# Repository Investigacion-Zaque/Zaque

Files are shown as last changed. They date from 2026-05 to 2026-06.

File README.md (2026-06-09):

# 🌾 Zaque - Monitoreo Agrícola Local Distribuido

> **Sistema de monitoreo de suelo para campesinos con IoT, sin dependencia de internet**

---

## 🎯 ¿Qué es Zaque?

Zaque es una **red de dispositivos ESP32 que monitorean cultivos** en múltiples puntos de una finca. El campesino enciende la zona móvil del celular, los ESP32 se conectan a esa red local, y puede ver todas las mediciones desde su navegador móvil **sin necesidad de internet**.

| Característica | Ventaja |
|---|---|
| 📡 **WiFi Local** | Sin necesidad de internet |
| 💾 **Almacenamiento Local** | Datos en microSD dentro del dispositivo |
| 📍 **GPS en cada nodo** | Sabe dónde se midió cada dato |
| 📊 **Dashboard web** | Visualiza desde el navegador del celular |
| 🤖 **Recomendaciones inteligentes** | Alertas de riego, fertilización, pH |
| ⚡ **Bajo consumo** | 1-3 meses de batería por nodo |
| 💰 **Bajo costo** | Hardware accesible (~USD $100 por nodo) |

---

## 🏗️ Arquitectura

```
┏━━━━━━━━━━━━━━━━━━━━━━━━━━━━━━━━━━━━━━━━━━┓
┃   Red WiFi Local del Celular 📱         ┃
┗━━━━━━━━━━━━━━━━━━━━━━━━━━━━━━━━━━━━━━━━━━┛
    △           △           △           △
    │           │           │           │
    │           │           │           │
┌───▼──┐    ┌───▼──┐    ┌───▼──┐    ┌─MAIN─┐
│SENSOR│    │SENSOR│    │SENSOR│    │MAIN  │
│  #1  │    │  #2  │    │  #3  │    │NODE  │
│      │    │      │    │      │    │      │
│📍GPS │    │📍GPS │    │📍GPS │    │📍GPS │
│📊SD  │    │📊SD  │    │📊SD  │    │📊SD  │
│🔋BAT │    │🔋BAT │    │🔋BAT │    │🔋BAT │
└───┬──┘    └───┬──┘    └───┬──┘    └─┬────┘
    │ HTTP       │ HTTP       │ HTTP    │ Servidor
    │ POST       │ POST       │ POST    │ Web
    └────────────┼────────────┼────────┘
                 │
                 ▼
        ┏━━━━━━━━━━━━━━━━━┓
        ┃  📊 Dashboard   ┃
        ┃  en Navegador   ┃
        ┃  (celular)      ┃
        ┗━━━━━━━━━━━━━━━━━┛
```

**Componentes:**

- **1 nodo MAIN**: Centro de procesamiento, servidor web, almacenamiento
- **N nodos SENSOR**: Distribuidos en la finca, envían mediciones
- **Red local WiFi**: Creada por el hotspot del celular
- **Almacenamiento**: Todos los datos en microSD local (sin nube)

---

## 📋 Estado del Proyecto (v0.2.0)

| Componente | Estado | Descripción |
|---|---|---|
| **Arquitectura** | ✅ Completado | Migración a local offline |
| **Firmware base** | ✅ Completado | zaque_device.ino con ambos roles |
| **Lectura de sensores** | ✅ Completado | RS485 Modbus (humedad, temp, pH, NPK) |
| **GPS** | ✅ Completado | Fallback a ubicación por defecto |
| **SD Logger** | ✅ Completado | CSV + JSON local |
| **WiFi Manager** | ✅ Completado | Conexión a redes locales |
| **Recomendaciones** | ✅ Completado | Motor de reglas de cultivo |
| **API REST** | 🔜 En progreso | Endpoints POST/GET |
| **Dashboard Web** | 🔜 Próximo | HTML embebido, mapas, históricos |
| **Múltiples sensores** | 🔜 Próximo | Escalabilidad 3+ nodos |
| **Sincronización nube** | 🔜 Futuro | MQTT/API remota opcional |

---

## 📊 Variables Medidas

| Variable | Unidad | Sensor | Rango |
|---|---|---|---|
| **Humedad del suelo** | % | RS485 Modbus | 0-100% |
| **Temperatura del suelo** | °C | RS485 Modbus | -10 a +60°C |
| **Conductividad eléctrica** | mS/cm | RS485 Modbus | 0-10 |
| **Potencial de hidrógeno (pH)** | pH | RS485 Modbus | 3.0-9.0 |
| **Nitrógeno (N)** | mg/kg | RS485 Modbus | 0-999 |
| **Fósforo (P)** | mg/kg | RS485 Modbus | 0-999 |
| **Potasio (K)** | mg/kg | RS485 Modbus | 0-999 |
| **Ubicación** | lat/lon | GPS NEO-6M | - |
| **Nivel de batería** | % | ADC ESP32 | 0-100% |

---

## 🤖 Recomendaciones Inteligentes

El sistema genera **alertas útiles al campesino** basadas en mediciones:

### 🔴 Alertas Críticas
- **Humedad < 25%**: "Riesgo de estrés hídrico severo. Revise riego lo antes posible."
- **Humedad > 85%**: "Riesgo de encharcamiento. Suspenda riego y revise drenaje."
- **Conductividad > 4.0 mS/cm**: "Posible exceso de sales. Suspenda fertilización."

### 🟠 Problemas Moderados
- **Humedad baja + Temperatura alta**: "Estrés hídrico. Revise riego urgentemente."
- **pH ácido + Fósforo bajo**: "Bloqueo nutricional. Revise corrección antes de fertilizar."
- **Humedad alta + Conductividad alta**: "Acumulación de sales. Evite fertilizar."

### 🟢 Recomendaciones Específicas
- **NPK bajo**: "Revise estado del cultivo y considere fertilización."
- **pH fuera de rango**: "Suelo ácido/alcalino. Consulte técnico para corrección."

### ✅ Estado Óptimo
- Cuando todo está bien: "Condiciones óptimas: Mantenga monitoreo."

---

## 🔌 Hardware Recomendado

**Idéntico para MAIN y SENSOR:**

```
┌─────────────────────────────────┐
│ ESP32 DevKit (WiFi + Bluetooth) │
├─────────────────────────────────┤
│ • Microcontrolador dual-core     │
│ • WiFi 802.11b/g/n              │
│ • 4 MB Flash + 520 KB RAM        │
│ • 36 pines GPIO                  │
└─────────────────────────────────┘
         │
    ┌────┴────┐
    │          │
    ▼          ▼
┌─────────┐ ┌─────────────────┐
│ Sensor  │ │ GPS + microSD   │
│ Modbus  │ │ + Batería       │
│ RS485   │ │ + Regulador     │
└─────────┘ └─────────────────┘
```

| Componente | Cantidad | Especificación | Costo |
|---|---|---|---|
| ESP32 DEVKIT | 1 | Microcontrolador WiFi | ~$15 |
| Sensor RS485 | 1 | NPK/Modbus multiparamétrico | ~$50 |
| Módulo GPS | 1 | NEO-6M (9600 bps) | ~$12 |
| microSD | 1 | 32GB FAT32 | ~$8 |
| Batería Li-Ion | 1 | 3.7V 2000mAh con BMS | ~$10 |
| Regulador DC-DC | 1 | 5V → 3.3V | ~$3 |
| **Total por nodo** | - | - | **~$100** |

---

## 📁 Estructura del Repositorio

```
Zaque/
│
├── 📦 firmware/
│   ├── zaque_device/              ← FIRMWARE UNIFICADO (MAIN/SENSOR)
│   │   ├── zaque_device.ino       ← Archivo principal
│   │   ├── config.h               ← Configuración (roles, pines, WiFi)
│   │   ├── types.h                ← Estructuras de datos e interfaces
│   │   ├── sensor_reader.cpp      ← Lectura RS485 Modbus
│   │   ├── gps_reader.cpp         ← Lectura GPS + fallback
│   │   ├── sd_logger.cpp          ← Logging en microSD
│   │   ├── wifi_manager.cpp       ← Gestión WiFi local
│   │   ├── http_client.cpp        ← Cliente HTTP (SENSOR)
│   │   ├── web_server.cpp         ← Servidor web (MAIN)
│   │   ├── node_registry.cpp      ← Registro de nodos (MAIN)
│   │   ├── recommendations.cpp    ← Motor de recomendaciones
│   │   └── dashboard_html.h       ← HTML/CSS/JS embebido
│   │
│   ├── Prueba_SD/                 ← Test de tarjeta SD
│   ├── Prueba_Sensor/             ← Test de sensor Modbus
│   └── legacy/                    ← Código anterior (referencia)
│
├── 📚 docs/
│   ├── arquitectura_offline_multinodo.md
│   ├── pinout.md
│   ├── protocolo_api_local.md
│   ├── hardware.md
│   ├── formato_sd.md
│   └── plan_migracion.md
│
├── 📄 Articulo/                   ← Artículo académico LaTeX
│   └── main.tex
│
├── 📋 README.md                   ← Este archivo
├── 📋 GUIA_FLASHEO_Y_USO.md       ← Guía de instalación
├── 📋 ZAQUE_RECOMMENDATION_ENGINE.md
├── 📋 informe_migracion_zaque_offline_multinodo.md
├── 📋 PIN_OUT.txt
└── 📋 LICENSE
```

---

## 🚀 Inicio Rápido

### 1️⃣ Configurar Firmware MAIN

```cpp
// En config.h:
#define DEVICE_ROLE DEVICE_ROLE_MAIN        // ✓ MAIN
#define NODE_ID "zaque"
#define NODE_NAME "Nodo principal - Casa finca"
#define WIFI_SSID "Zaque"                   // Tu zona móvil
#define WIFI_PASSWORD "free12345"
#define DEFAULT_LATITUDE 4.6632              // Ubicación por defecto (GPS fallback)
#define DEFAULT_LONGITUDE -74.0550
```

**En Arduino IDE:**
- Abrir: `firmware/zaque_device/zaque_device.ino`
- Seleccionar: Board → ESP32 Dev Module
- Puerto: COM/ttyUSB
- Subir

### 2️⃣ Configurar Firmware SENSOR

```cpp
// En config.h:
#define DEVICE_ROLE DEVICE_ROLE_SENSOR      // ✓ SENSOR
#define NODE_ID "zona_2"
#define NODE_NAME "Lote de maiz"
#define MAIN_HOST "zaque.local"             // IP/hostname del MAIN
```

Cambiar y subir a otro ESP32.

### 3️⃣ Ejecutar en Campo

```
1. Enciende zona móvil del celular ("Zaque")
2. Enciende ESP32 MAIN
   └─→ Se conecta a WiFi
   └─→ Levanta servidor en http://zaque.local
   └─→ Toma medición local
   └─→ Espera sensores
3. Enciende ESP32 SENSOR(es)
   └─→ Se conectan a WiFi
   └─→ Toman mediciones
   └─→ Envían al MAIN por HTTP POST
   └─→ Entran en deep sleep (ahorro energía)
4. Abre navegador en celular
   └─→ Entra a http://zaque.local
   └─→ Ve dashboard con todos los nodos
   └─→ Lee recomendaciones
```

---

## 📡 API REST Local

### Endpoints del MAIN

| Método | Ruta | Descripción |
|---|---|---|
| **GET** | `/` | Dashboard HTML interactivo |
| **GET** | `/api/status` | Estado general del sistema |
| **GET** | `/api/nodes` | Lista de nodos activos |
| **GET** | `/api/latest` | Última medición por nodo |
| **POST** | `/api/measurements` | Recibir medición (SENSOR → MAIN) |
| **GET** | `/download/measurements.csv` | Descargar histórico |

### Ejemplo: Enviar Medición

```bash
curl -X POST http://zaque.local/api/measurements \
  -H "Content-Type: application/json" \
  -d '{
    "api_key": "ZAQUE_LOCAL_KEY",
    "node_id": "zona_2",
    "node_name": "Lote de maiz",
    "latitude": 4.6632,
    "longitude": -74.0550,
    "soil_humidity": 64.0,
    "soil_temperature": 22.5,
    "electrical_conductivity": 1.2,
    "ph": 6.2,
    "nitrogen": 34,
    "phosphorus": 18,
    "potassium": 41,
    "battery_percent": 83
  }'
```

---

## 💾 Almacenamiento en microSD

**Archivos creados automáticamente:**

```
/measurements.csv
  timestamp,node_id,node_name,lat,lon,soil_temperature,soil_humidity,...
  1715609400,zona_2,Lote de maiz,4.6632,-74.0550,22.5,64.0,...

/latest.json
  {
    "updated_at": "1715609400",
    "nodes": [
      {
        "node_id": "zona_2",
        "soil_humidity": 64.0,
        "ph": 6.2,
        "recommendation": "✅ Condiciones óptimas: Mantenga monitoreo."
      }
    ]
  }

/logs/system.log
  [DEBUG] GPS reader initialized
  [INFO] Measurement logged to SD
  [WARNING] Battery low: 15%
```

---

## ⚡ Consumo de Energía

### Nodo SENSOR típico
```
Medición:      ~5 seg
Envío HTTP:    ~2 seg
Deep Sleep:    ~30 min

Consumo promedio: ~0.5 mA (en deep sleep)
Batería típica:   2000 mAh
Autonomía:        ≈ 1-3 meses
```

### Nodo MAIN (siempre activo)
```
WiFi siempre conectado
Dashboard activo
Consumo: ~80-150 mA promedio

Nota: MAIN debe estar conectado a alimentación (AC/solar)
```

---

## 🔐 Seguridad

| Aspecto | MVP (Actual) | Futuro |
|---|---|---|
| **Red** | WiFi local | WiFi local + VPN opcional |
| **API Key** | Hardcodeada | JWT tokens |
| **HTTPS** | No necesario | Sí, cuando haya internet |
| **Autenticación** | Ninguna | Por nodo |
| **Datos** | Almacenamiento local | Encriptación opcional |

---

## 📚 Documentación Completa

| Documento | Contenido |
|---|---|
| 📖 **`docs/arquitectura_offline_multinodo.md`** | Detalles arquitectura distribuida |
| 🔌 **`docs/pinout.md`** | Asignación de pines ESP32 y conflictos |
| 📡 **`docs/protocolo_api_local.md`** | Especificación completa de API |
| 🔧 **`docs/hardware.md`** | Recomendaciones y esquemáticos |
| 💾 **`docs/formato_sd.md`** | Estructura de archivos SD |
| 📋 **`docs/plan_migracion.md`** | Fases de implementación |
| 🤖 **`ZAQUE_RECOMMENDATION_ENGINE.md`** | Motor de recomendaciones |
| 📊 **`informe_migracion_zaque_offline_multinodo.md`** | Informe técnico completo |
| 🚀 **`GUIA_FLASHEO_Y_USO.md`** | Paso a paso de instalación |

---

## 🛠️ Desarrollo Local

### Compilar en Arduino IDE

```bash
# Abrir archivo
Arduino IDE → File → Open → firmware/zaque_device/zaque_device.ino

# Configurar placa
Tools → Board → ESP32 Dev Module
Tools → Port → /dev/ttyUSB0 (o COM3 en Windows)

# Compilar y subir
Sketch → Upload (Ctrl+U)
```

### Ver logs

```bash
# Monitor serial en Arduino IDE
Tools → Serial Monitor
Configurar: 115200 baud
```

### Debug

```cpp
// En config.h:
#define ENABLE_DEBUG_SERIAL true        // Habilita logs

// En código:
#if ENABLE_DEBUG_SERIAL
  Serial.println("✓ Mi mensaje de debug");
#endif
```

---

## 🎯 Próximas Fases

### 🔜 Phase 1: MAIN Autónomo
- [x] Lectura sensor Modbus
- [x] Lectura GPS
- [x] Almacenamiento SD
- [ ] Servidor web básico
- [ ] Dashboard HTML

### 🔜 Phase 2: API Local
- [ ] Endpoint POST /api/measurements
- [ ] Validación de datos
- [ ] Manejo de errores

### 🔜 Phase 3: Firmware SENSOR
- [ ] Lectura de sensores
- [ ] Envío HTTP al MAIN
- [ ] Deep sleep

### 🔜 Phase 4: Escalabilidad
- [ ] Soporte 3+ nodos
- [ ] Descubrimiento automático (mDNS)
- [ ] Sincronización de estado

### 🔜 Phase 5: Recomendaciones
- [ ] Motor de reglas completo
- [ ] Análisis predictivo
- [ ] Recomendaciones por cultivo

### 🔜 Phase 6-7: Futuro
- [ ] Sincronización con nube (opcional)
- [ ] IA para predicción
- [ ] Interfaz mejorada

---

## 📞 Preguntas Frecuentes

| Pregunta | Respuesta |
|---|---|
| **¿Necesito internet?** | No. Zaque funciona 100% offline con red WiFi local del celular. |
| **¿Cuánto cuesta?** | ~$100 USD por nodo (hardware accesible). |
| **¿Cuántos sensores?** | Teóricamente ilimitados. Límite práctico: rango WiFi (~50m). |
| **¿Si falla GPS?** | Se usa ubicación por defecto automáticamente, sin alertas. |
| **¿Se pierden datos sin internet?** | No. Todo se guarda localmente en microSD. |
| **¿Compatible con otros sensores?** | Sí, arquitectura modular permite integrar RS485/Modbus. |

---

## 📄 Licencia

```
ZAQUE - Sistema de Monitoreo Agrícola Local Distribuido
Copyright (C) 2026 Alejandro Roa, Laura Holguín, Andrés Guarnizo

This program is free software: you can redistribute it and/or modify
it under the terms of the GNU General Public License as published by
the Free Software Foundation, either version 3 of the License.
```

Ver [LICENSE](LICENSE) para más detalles.

---

## 👥 Autores

- 🧑‍💻 **Alejandro Roa Aparicio** – Desarrollo firmware, arquitectura
- 👩‍💼 **Laura Sofía Holguín Giraldo** – Análisis agrícola, documentación
- 🔧 **Andrés Felipe Guarnizo Saavedra** – Hardware, integración sensores

---

<div align="center">

**🌾 Zaque: Empoderando a campesinos con tecnología accesible 🌾**

*Monitoreo inteligente, local, sin dependencia de internet.*

[📖 Documentación Completa](docs/) • [📱 Hardware](docs/hardware.md) • [🚀 Inicio Rápido](#-inicio-rápido) • [🤖 Recomendaciones](ZAQUE_RECOMMENDATION_ENGINE.md)

</div>

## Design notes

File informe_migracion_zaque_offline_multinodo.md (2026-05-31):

# Informe técnico: Migración de Zaque hacia una red local multinodo con dashboard offline

## 1. Resumen ejecutivo

El proyecto **Zaque** actualmente está planteado como un sistema de monitoreo ambiental de suelos para comunidades campesinas de Colombia. La arquitectura actual usa nodos ESP32 que miden variables del suelo y envían datos mediante **ESP-NOW** hacia un receptor/gateway, el cual publica la información por **MQTT** hacia un servidor Node.js y una base de datos MySQL.

La nueva versión propuesta cambia el enfoque hacia una arquitectura **local, autónoma y tolerante a falta de internet**, donde un campesino pueda encender la zona móvil de su celular, conectar varios dispositivos ESP32 a esa red local y visualizar las mediciones de diferentes puntos de la finca desde una página web levantada por un nodo principal.

La propuesta consiste en migrar el proyecto hacia una arquitectura con:

- Un **nodo MAIN**, que funciona como estación principal.
- Varios **nodos SENSOR**, que funcionan como puntos distribuidos de medición.
- Mismo hardware para todos los dispositivos.
- Diferencia únicamente por firmware o configuración.
- Comunicación por WiFi local usando la red del celular.
- Dashboard web servido desde el nodo MAIN.
- Almacenamiento local en microSD.
- GPS en cada nodo para georreferenciar las mediciones.
- Recomendaciones agrícolas básicas por zona.
- MQTT y nube como modo opcional futuro, no como dependencia principal.

---

## 2. Estado actual del repositorio

Según la estructura actual del repositorio, Zaque contiene los siguientes módulos principales:

```text
Zaque/
├── ESP32/
├── Base de datos/
├── Api/
├── Frontend/
├── Backend/
├── README.md
└── LICENSE
```

El README actual describe una arquitectura basada en:

```text
[ESP32 Emisor] ──ESP-NOW──> [ESP32 Receptor] ──MQTT──> [Servidor Node.js] ──> [MySQL]
```

Los componentes actuales relevantes son:

| Componente actual | Estado | Uso actual |
| --- | ---: | --- |
| `ESP32/ESPNOW_bajo_consumo_emisor.ino`  | Funcional | Nodo sensor que lee RS485/Modbus, envía por ESP-NOW y entra en deep sleep. |
| `ESP32/Receptor_con_MQTT_y_Bateria.ino` | Funcional | Nodo receptor/gateway que recibe ESP-NOW y publica por MQTT. |
| `Base de datos/server.js` | Funcional | Servidor Node.js con cliente MQTT y persistencia en MySQL. |
| `Api/` | Pendiente | REST API futura. |
| `Frontend/` | Pendiente | Dashboard futuro. |
| `Backend/` | Pendiente | Lógica de negocio futura. |

La versión actual ya tiene una base valiosa:

- Lectura de sensor NPK por RS485/Modbus.
- Comunicación entre ESP32.
- Medición de batería.
- Deep sleep para bajo consumo.
- Separación entre nodo sensor y nodo receptor.
- Backend inicial para recibir datos por MQTT.

Sin embargo, el nuevo objetivo requiere reducir la dependencia de internet y de infraestructura externa.

---

## 3. Nuevo objetivo del proyecto

El nuevo objetivo de Zaque es convertirse en una **red local de monitoreo agrícola distribuido**, donde un campesino pueda consultar información del suelo de diferentes zonas de su finca sin depender de internet.

La nueva idea central es:

> Un conjunto de dispositivos ESP32 con el mismo hardware, distribuidos en distintos puntos de una finca. Uno de ellos se configura como nodo MAIN y levanta un dashboard web local. Los demás se configuran como nodos SENSOR y envían sus mediciones al MAIN mediante la red WiFi creada por el celular del campesino. Cada nodo guarda sus datos localmente en microSD y reporta mediciones georreferenciadas con GPS.

---

## 4. Arquitectura propuesta

### 4.1 Arquitectura general

```text
Red WiFi local del celular
                                  │
                                  │
        ┌─────────────────────────┼─────────────────────────┐
        │                         │                         │
        ▼                         ▼                         ▼
┌─────────────────┐       ┌─────────────────┐       ┌─────────────────┐
│ ESP32 SENSOR 1  │       │ ESP32 SENSOR 2  │       │ ESP32 SENSOR N  │
│ Sensor suelo    │       │ Sensor suelo    │       │ Sensor suelo    │
│ GPS             │       │ GPS             │       │ GPS             │
│ microSD         │       │ microSD         │       │ microSD         │
│ Batería         │       │ Batería         │       │ Batería         │
└────────┬────────┘       └────────┬────────┘       └────────┬────────┘
         │                         │                         │
         │ HTTP/JSON               │ HTTP/JSON               │ HTTP/JSON
         └─────────────────────────┼─────────────────────────┘
                                   ▼
                         ┌─────────────────┐
                         │ ESP32 MAIN      │
                         │ Sensor suelo    │
                         │ GPS             │
                         │ microSD         │
                         │ Web dashboard   │
                         │ API local       │
                         │ Recomendaciones │
                         └────────┬────────┘
                                  │
                                  │ HTTP local
                                  ▼
                         ┌─────────────────┐
                         │ Celular         │
                         │ Navegador web   │
                         │ Dashboard Zaque │
                         └─────────────────┘
```

### 4.2 Roles del sistema

#### Nodo MAIN

El nodo MAIN es un dispositivo completo. No es solo un gateway; también mide su propia zona.

Funciones:

- Conectarse al WiFi del celular.
- Leer su propio sensor de suelo.
- Leer GPS.
- Guardar sus propias mediciones en microSD.
- Levantar un servidor web local.
- Exponer una API HTTP para recibir datos de otros nodos.
- Guardar las mediciones recibidas de los nodos SENSOR.
- Calcular o asignar recomendaciones agrícolas básicas.
- Mostrar dashboard con todos los puntos de medición.
- Permitir descarga de archivos CSV o JSON.

#### Nodo SENSOR

El nodo SENSOR tiene el mismo hardware que el MAIN, pero ejecuta un firmware distinto o una configuración diferente.

Funciones:

- Conectarse al WiFi del celular.
- Leer sensor de suelo.
- Leer GPS.
- Guardar copia local en microSD.
- Buscar o conocer la IP del nodo MAIN.
- Enviar mediciones por HTTP/JSON al nodo MAIN.
- Reintentar envío si falla.
- Dormir entre mediciones para ahorrar batería.

---

## 5. Decisión clave: mismo hardware, firmware diferente

Una de las mejores decisiones del nuevo diseño es que todos los dispositivos compartan el mismo hardware:

```text
ESP32 + sensor de suelo RS485/Modbus + GPS + microSD + batería
```

La diferencia se define por software:

```cpp
#define DEVICE_ROLE_MAIN 1
#define DEVICE_ROLE_SENSOR 2

#define DEVICE_ROLE DEVICE_ROLE_MAIN
// #define DEVICE_ROLE DEVICE_ROLE_SENSOR
```

Ventajas:

- Simplifica compras y ensamblaje.
- Facilita mantenimiento.
- Permite reemplazar un MAIN por un SENSOR cambiando firmware.
- Permite escalar de 1 nodo a muchos nodos.
- Reduce errores de cableado por diseños diferentes.
- Facilita documentar un solo diagrama de hardware.

---

## 6. Comparación entre arquitectura actual y nueva arquitectura

| Aspecto | Arquitectura actual | Nueva arquitectura propuesta |
| --- | --- | --- |
| Comunicación entre nodos | ESP-NOW | WiFi local del celular + HTTP/JSON |
| Salida principal de datos | MQTT hacia servidor | Dashboard web local en el MAIN |
| Dependencia de internet | Alta | Baja o nula |
| Almacenamiento | MySQL en servidor | microSD local en MAIN y sensores |
| Visualización | Frontend pendiente | Web embebida en ESP32 MAIN |
| Escalabilidad local | Emisor + receptor | 1 MAIN + muchos SENSOR |
| GPS | No central en diseño actual | GPS por nodo |
| Recomendaciones | Backend futuro | Reglas locales por zona |
| Uso en campo sin internet | Limitado | Principal objetivo |
| Nube/MQTT | Principal | Opcional futuro |

---

## 7. Flujo de operación propuesto

### 7.1 Flujo para el campesino

```text
1. El campesino prende la zona móvil del celular.
2. Enciende el nodo MAIN.
3. Enciende los nodos SENSOR distribuidos en la finca.
4. Todos los ESP32 se conectan a la red WiFi local del celular.
5. El MAIN levanta el dashboard web.
6. Los SENSOR toman mediciones y las envían al MAIN.
7. El campesino abre el navegador del celular.
8. Entra a la IP del MAIN o a zaque.local si mDNS funciona.
9. Visualiza mediciones, coordenadas, batería y recomendaciones por zona.
```

### 7.2 Flujo técnico del nodo MAIN

```text
Inicio
  ↓
Cargar configuración
  ↓
Inicializar sensor RS485/Modbus
  ↓
Inicializar GPS
  ↓
Inicializar microSD
  ↓
Conectarse al WiFi del celular
  ↓
Levantar servidor web
  ↓
Levantar API local
  ↓
Tomar medición propia
  ↓
Guardar medición propia en SD
  ↓
Recibir mediciones de sensores
  ↓
Guardar mediciones recibidas
  ↓
Actualizar archivo resumen
  ↓
Mostrar dashboard
```

### 7.3 Flujo técnico del nodo SENSOR

```text
Inicio
  ↓
Cargar configuración del nodo
  ↓
Inicializar sensor RS485/Modbus
  ↓
Inicializar GPS
  ↓
Inicializar microSD
  ↓
Conectarse al WiFi del celular
  ↓
Encontrar MAIN
  ↓
Tomar medición
  ↓
Guardar medición local en SD
  ↓
Enviar medición al MAIN por HTTP POST
  ↓
Si envío correcto: marcar como sincronizado
  ↓
Si envío falla: dejar pendiente para reintento
  ↓
Entrar en deep sleep
```

---

## 8. Comunicación entre SENSOR y MAIN

### 8.1 Protocolo recomendado

Para esta nueva versión, se recomienda usar:

```text
WiFi local + HTTP + JSON
```

Motivos:

- Es fácil de implementar.
- Es fácil de depurar con navegador, Postman o curl.
- Se integra naturalmente con el servidor web del MAIN.
- Permite que los sensores usen una API clara.
- Facilita migrar después a una API externa o sincronización en nube.

### 8.2 Rutas HTTP sugeridas en el MAIN

```text
GET  /
GET  /dashboard
GET  /api/status
GET  /api/nodes
GET  /api/measurements/latest
GET  /api/history?node_id=zona_1
POST /api/measurements
GET  /download/measurements.csv
```

### 8.3 Payload JSON enviado por cada SENSOR

```json
{
  "node_id": "zona_2",
  "node_name": "Lote de maiz",
  "role": "sensor",
  "timestamp": "2026-05-30T16:20:00",
  "lat": 4.7112,
  "lon": -74.0721,
  "soil_temperature": 22.8,
  "soil_humidity": 64.0,
  "electrical_conductivity": 820,
  "ph": 6.2,
  "nitrogen": 34,
  "phosphorus": 18,
  "potassium": 41,
  "battery_percent": 83,
  "firmware_version": "0.2.0"
}
```

### 8.4 Respuesta del MAIN

```json
{
  "status": "ok",
  "stored": true,
  "recommendation": "Humedad adecuada y pH dentro de rango aceptable.",
  "server_time": "2026-05-30T16:20:05"
}
```

---

## 9. Descubrimiento del nodo MAIN

Uno de los retos principales es que los nodos SENSOR necesitan saber la dirección IP del MAIN.

Se proponen implementación.

### mDNS

El MAIN se anuncia como:

```text
zaque.local
```

Los sensores intentan enviar a:

```text
http://zaque.local/api/measurements
```

Ventaja:

- Más amigable.
- No requiere conocer IP.

Desventaja:

- Puede fallar en algunos celulares o redes.

## 10. Almacenamiento en microSD

### 10.1 Por qué usar SD en todos los nodos

Aunque el MAIN guarde todos los datos, conviene que cada SENSOR también tenga microSD.

Ventajas:

- Si no hay conexión con el MAIN, el SENSOR no pierde datos.
- Cada nodo tiene respaldo local.
- Se puede recuperar información directamente desde la SD.
- Permite sincronización posterior.
- Mejora la confiabilidad en campo.

### 10.2 Archivos recomendados en el MAIN

```text
/sd/
├── config.json
├── nodes.json
├── latest.json
├── measurements.csv
├── recommendations.csv
└── logs/
    └── system.log
```

### 10.3 Archivos recomendados en cada SENSOR

```text
/sd/
├── config.json
├── local_measurements.csv
├── pending_queue.csv
└── logs/
    └── sensor.log
```

### 10.4 Formato CSV global del MAIN

```csv
timestamp,node_id,node_name,lat,lon,soil_temperature,soil_humidity,electrical_conductivity,ph,nitrogen,phosphorus,potassium,battery_percent,recommendation
2026-05-30T16:20:00,zona_2,Lote de maiz,4.7112,-74.0721,22.8,64,820,6.2,34,18,41,83,"Humedad adecuada y pH aceptable"
```

### 10.5 Archivo `latest.json`

Este archivo facilita que el dashboard cargue rápidamente la última medición de cada nodo.

```json
{
  "updated_at": "2026-05-30T16:20:05",
  "nodes": [
    {
      "node_id": "main",
      "node_name": "Nodo principal",
      "role": "main",
      "lat": 4.7110,
      "lon": -74.0710,
      "soil_humidity": 58,
      "ph": 6.4,
      "nitrogen": 35,
      "phosphorus": 20,
      "potassium": 40,
      "battery_percent": 91,
      "last_seen": "2026-05-30T16:19:00",
      "recommendation": "Condiciones estables."
    },
    {
      "node_id": "zona_2",
      "node_name": "Lote de maiz",
      "role": "sensor",
      "lat": 4.7112,
      "lon": -74.0721,
      "soil_humidity": 64,
      "ph": 6.2,
      "nitrogen": 34,
      "phosphorus": 18,
      "potassium": 41,
      "battery_percent": 83,
      "last_seen": "2026-05-30T16:20:00",
      "recommendation": "Humedad adecuada y pH aceptable."
    }
  ]
}
```

---

## 11. Recomendaciones agrícolas locales

La primera versión no debería intentar usar inteligencia artificial compleja. Se recomienda comenzar con un motor de reglas simple, explicable y fácil de ajustar.

### 11.1 Variables consideradas

- Humedad del suelo.
- pH.
- Conductividad eléctrica.
- Nitrógeno.
- Fósforo.
- Potasio.
- Temperatura del suelo.
- Batería del nodo.

### 11.2 Ejemplo de reglas iniciales

```text
Si humedad < umbral_bajo:
  Recomendar revisar riego.

Si pH < 5.5:
  Indicar posible acidez del suelo.

Si pH > 7.5:
  Indicar posible alcalinidad del suelo.

Si conductividad es muy alta:
  Alertar posible exceso de sales.

Si N, P o K están bajos:
  Recomendar revisar fertilización según cultivo.

Si batería < 20%:
  Recomendar recargar o revisar alimentación del nodo.
```

### 11.3 Recomendación importante

Las recomendaciones deben mostrarse como orientación, no como diagnóstico absoluto.

Texto sugerido para el dashboard:

> Las recomendaciones son orientativas y deben ajustarse según el cultivo, etapa de crecimiento, tipo de suelo y acompañamiento técnico local.

---

## 12. Dashboard web local

### 12.1 Objetivo del dashboard

El dashboard debe ser simple, liviano y funcional en celulares.

Debe permitir:

- Ver todos los nodos conectados.
- Ver última medición por zona.
- Ver coordenadas GPS.
- Ver batería de cada nodo.
- Ver recomendaciones por zona.
- Ver histórico básico.
- Descargar CSV.
- Identificar nodos sin conexión reciente.

### 12.2 Vista principal sugerida

```text
Zaque - Monitoreo local de finca

Resumen:
- Nodos registrados: 4
- Nodos activos: 3
- Alertas: 2
- Última actualización: hace 1 minuto

[MAIN - Casa finca]
Humedad: 58%
PH: 6.4
NPK: 35 / 20 / 40
Batería: 91%
Recomendación: Condiciones estables.

[Zona 2 - Lote de maíz]
Humedad: 34%
PH: 5.3
NPK: 18 / 10 / 24
Batería: 76%
Recomendación: Humedad baja y pH ácido. Revisar riego y corrección del suelo.
```

### 12.3 Mapa offline

Como no se puede depender de Google Maps o mapas online si no hay internet, se recomienda iniciar con dos opciones:

#### Opción básica

Mostrar coordenadas GPS en texto:

```text
Zona 1: 4.7112, -74.0721
Zona 2: 4.7120, -74.0730
```

#### Opción intermedia

Crear un mapa relativo de finca usando las diferencias entre coordenadas:

```text
Zona 2
           ●

Zona 1 ●          ● Zona 3

           ●
         MAIN
```

Este mapa no requiere internet y puede renderizarse con HTML, CSS y JavaScript sencillo.

---

## 13. Nueva estructura recomendada del repositorio

Se recomienda no borrar de inmediato la arquitectura anterior. Lo mejor es migrar progresivamente y dejar el modo MQTT como referencia o modo online futuro.

```text
Zaque/
├── firmware/
│   ├── zaque_device/
│   │   ├── zaque_device.ino
│   │   ├── config.h
│   │   ├── roles.h
│   │   ├── sensor_reader.cpp
│   │   ├── sensor_reader.h
│   │   ├── gps_reader.cpp
│   │   ├── gps_reader.h
│   │   ├── sd_logger.cpp
│   │   ├── sd_logger.h
│   │   ├── wifi_manager.cpp
│   │   ├── wifi_manager.h
│   │   ├── http_client.cpp
│   │   ├── http_client.h
│   │   ├── web_server.cpp
│   │   ├── web_server.h
│   │   ├── recommendations.cpp
│   │   ├── recommendations.h
│   │   ├── node_registry.cpp
│   │   ├── node_registry.h
│   │   └── dashboard_html.h
│   │
│   └── legacy/
│       ├── ESPNOW_bajo_consumo_emisor.ino
│       └── Receptor_con_MQTT_y_Bateria.ino
│
├── docs/
│   ├── arquitectura_offline_multinodo.md
│   ├── hardware.md
│   ├── pinout.md
│   ├── protocolo_api_local.md
│   ├── formato_sd.md
│   ├── recomendaciones.md
│   └── plan_migracion.md
│
├── dashboard/
│   ├── prototype.html
│   ├── styles.css
│   └── app.js
│
├── tools/
│   ├── csv_to_json.py
│   └── sd_validator.py
│
├── cloud_optional/
│   ├── mqtt_bridge/
│   ├── api/
│   └── database/
│
├── README.md
└── LICENSE
```

### 13.1 Qué hacer con las carpetas actuales

| Carpeta actual | Acción recomendada |
| --- | --- |
| `ESP32/` | Migrar a`firmware/legacy/` y crear `firmware/zaque_device/`. |
| `Base de datos/` | Mover a`cloud_optional/mqtt_bridge/` o mantener como modo online. |
| `Api/` | Usar para futura API externa, no para MVP offline. |
| `Frontend/` | Usar como prototipo visual; la versión embebida debe vivir en`dashboard_html.h`. |
| `Backend/` | Reservar para lógica futura de nube o sincronización. |
| `README.md` | Actualizar con la nueva arquitectura offline multinodo. |

---

## 14. Firmware unificado por roles

### 14.1 Archivo `config.h`

```cpp
#pragma once

#define DEVICE_ROLE_MAIN 1
#define DEVICE_ROLE_SENSOR 2

#define DEVICE_ROLE DEVICE_ROLE_MAIN

#define NODE_ID "main"
#define NODE_NAME "Nodo principal - Casa finca"
#define FIRMWARE_VERSION "0.2.0"

#define WIFI_SSID "NombreZonaMovil"
#define WIFI_PASSWORD "ClaveZonaMovil"

#define MAIN_HOST "zaque.local"
#define MAIN_IP_FALLBACK "192.168.43.50"
#define MAIN_PORT 80

#define MEASUREMENT_INTERVAL_MINUTES 30
```

Para un sensor:

```cpp
#define DEVICE_ROLE DEVICE_ROLE_SENSOR
#define NODE_ID "zona_2"
#define NODE_NAME "Lote de maiz"
```

### 14.2 Pseudocódigo principal

```cpp
#include "config.h"
#include "sensor_reader.h"
#include "gps_reader.h"
#include "sd_logger.h"
#include "wifi_manager.h"
#include "recommendations.h"

#if DEVICE_ROLE == DEVICE_ROLE_MAIN
#include "web_server.h"
#include "node_registry.h"
#endif

#if DEVICE_ROLE == DEVICE_ROLE_SENSOR
#include "http_client.h"
#endif

void setup() {
  initSerial();
  initSensor();
  initGPS();
  initSD();
  connectWiFi();

#if DEVICE_ROLE == DEVICE_ROLE_MAIN
  initNodeRegistry();
  startWebServer();
#endif
}

void loop() {
  Measurement m = readMeasurement();
  m.recommendation = buildRecommendation(m);
  saveMeasurementToSD(m);

#if DEVICE_ROLE == DEVICE_ROLE_MAIN
  updateLocalNode(m);
  handleWebServer();
#endif

#if DEVICE_ROLE == DEVICE_ROLE_SENSOR
  bool sent = sendMeasurementToMain(m);
  if (!sent) {
    savePendingMeasurement(m);
  }
  goToDeepSleep(MEASUREMENT_INTERVAL_MINUTES);
#endif
}
```

---

## 15. Migración del código actual

### 15.1 Reutilizar del emisor actual

Del archivo actual del emisor ESP-NOW se puede reutilizar:

- Inicialización del sensor RS485/Modbus.
- Lectura de variables del suelo.
- Cálculo de batería.
- Estructura de medición.
- Lógica de deep sleep.

Cambios necesarios:

- Reemplazar envío ESP-NOW por HTTP POST.
- Agregar GPS.
- Agregar microSD.
- Agregar reintento de envío.
- Agregar cola de datos pendientes.

### 15.2 Reutilizar del receptor actual

Del archivo actual del receptor con MQTT se puede reutilizar:

- Idea de gateway central.
- Manejo de WiFi.
- Manejo de datos recibidos.
- Estructura de publicación de datos.

Cambios necesarios:

- Reemplazar publicación MQTT por almacenamiento en SD.
- Agregar servidor web embebido.
- Agregar API HTTP local.
- Agregar lectura del sensor propio del MAIN.
- Agregar GPS propio.
- Agregar dashboard.

### 15.3 Reutilizar del backend Node.js

El servidor Node.js actual no debe ser eliminado. Se recomienda moverlo a una carpeta de modo online opcional.

Uso futuro:

- Sincronización cuando haya internet.
- Carga de CSV históricos.
- Panel web en nube.
- Respaldo de datos.
- Análisis avanzado.

---

## 16. Plan de migración por fases

### Fase 1: MAIN autónomo de un solo nodo

Objetivo:

```text
Un solo ESP32 mide, guarda en SD y levanta web local.
```

Tareas:

- Integrar lectura del sensor actual.
- Agregar GPS.
- Agregar microSD.
- Crear archivo CSV local.
- Levantar servidor web simple.
- Mostrar última medición.

Resultado esperado:

```text
ESP32 MAIN → Dashboard local con su propia medición
```

### Fase 2: API local del MAIN

Objetivo:

```text
Permitir que otros nodos envíen mediciones al MAIN.
```

Tareas:

- Crear endpoint `POST /api/measurements`.
- Validar JSON recibido.
- Guardar medición en `measurements.csv`.
- Actualizar `latest.json`.
- Responder con recomendación.

Resultado esperado:

```text
curl o Postman puede enviar una medición falsa al MAIN y aparece en el dashboard.
```

### Fase 3: Firmware SENSOR

Objetivo:

```text
Un nodo SENSOR mide y envía datos reales al MAIN.
```

Tareas:

- Configurar firmware como SENSOR.
- Conectar al WiFi del celular.
- Leer sensor y GPS.
- Guardar localmente en SD.
- Enviar JSON al MAIN.
- Implementar reintento si falla.
- Implementar deep sleep.

Resultado esperado:

```text
SENSOR → HTTP POST → MAIN → SD → Dashboard
```

### Fase 4: Múltiples sensores

Objetivo:

```text
Escalar a 3 o más puntos de medición.
```

Tareas:

- Crear IDs únicos por nodo.
- Mostrar tarjetas por nodo.
- Detectar último contacto.
- Marcar nodos inactivos.
- Mostrar batería por nodo.

Resultado esperado:

```text
Dashboard con MAIN + SENSOR 1 + SENSOR 2 + SENSOR 3
```

### Fase 5: Recomendaciones por zona

Objetivo:

```text
Mostrar alertas y recomendaciones por nodo.
```

Tareas:

- Crear `recommendations.cpp`.
- Definir reglas base.
- Asociar recomendaciones a cada medición.
- Mostrar nivel de alerta.

Resultado esperado:

```text
Cada zona muestra estado: estable, atención, crítico.
```

### Fase 6: Descubrimiento automático del MAIN

Objetivo:

```text
Evitar depender de IP fija.
```

Tareas:

- Implementar mDNS `zaque.local`.
- Implementar fallback por IP.
- Implementar UDP discovery si mDNS falla.

Resultado esperado:

```text
Los sensores encuentran al MAIN automáticamente.
```

### Fase 7: Sincronización opcional con nube

Objetivo:

```text
Recuperar MQTT/API solo cuando haya internet.
```

Tareas:

- Crear módulo opcional `cloud_sync`.
- Subir CSV o JSON a servidor.
- Reusar servidor Node.js actual.
- Mantener modo offline como prioridad.

Resultado esperado:

```text
Zaque funciona sin internet, pero puede sincronizar cuando haya conexión.
```

---

## 17. Librerías sugeridas para ESP32

### Para firmware Arduino

```text
ModbusMaster       → sensor RS485/Modbus
TinyGPSPlus        → lectura GPS
SD                 → tarjeta microSD
SPI                → comunicación con SD
WiFi               → conexión al hotspot
WebServer          → servidor HTTP simple
HTTPClient         → envío HTTP desde SENSOR a MAIN
ArduinoJson        → manejo de JSON
ESPmDNS            → zaque.local
```

### Notas

- Si el dashboard crece mucho, considerar `ESPAsyncWebServer`, pero para iniciar basta con `WebServer`.
- `ArduinoJson` debe usarse con documentos pequeños para no saturar memoria.
- El HTML del dashboard debe ser liviano.

---

## 18. Consideraciones de hardware

### 18.1 Hardware base por nodo

Cada nodo tendría:

```text
- ESP32
- Sensor de suelo RS485/Modbus NPK
- Módulo RS485 tipo HW-519 o equivalente
- Módulo GPS
- Módulo microSD
- Batería
- Regulador de voltaje adecuado
- Caja protectora
```

### 18.2 Recomendación de pines

Se debe diseñar un pinout definitivo evitando conflictos entre:

- UART del sensor RS485.
- UART del GPS.
- SPI de la microSD.
- ADC para batería.
- Pines de boot del ESP32.

Ejemplo conceptual:

```text
RS485/Modbus → UART2
GPS          → UART1
microSD      → SPI
Batería      → ADC
```

### 18.3 Riesgos de hardware

- El GPS puede consumir bastante energía.
- La SD puede corromper datos si se apaga durante escritura.
- El sensor RS485 puede requerir alimentación diferente al ESP32.
- El WiFi consume más que ESP-NOW.
- El hotspot del celular puede limitar el número de dispositivos conectados.

---

## 19. Energía y bajo consumo

Para nodos SENSOR se recomienda:

```text
Despertar → conectar WiFi → medir → guardar SD → enviar → dormir
```

Intervalos sugeridos:

```text
15 minutos: monitoreo más frecuente
30 minutos: equilibrio entre datos y batería
60 minutos: mayor autonomía
```

El MAIN probablemente debe permanecer activo mientras el campesino consulta el dashboard. Se puede considerar un modo donde el MAIN también duerma cuando no se necesita la web, pero para el MVP debe permanecer encendido.

---

## 20. Seguridad mínima

Aunque el sistema sea local, conviene implementar seguridad básica.

Recomendaciones:

- No dejar contraseñas reales en GitHub.
- Mantener `secrets.h` fuera del repositorio.
- Usar `secrets_example.h` como plantilla.
- Agregar un token simple para que solo nodos autorizados envíen datos.

Ejemplo:

```json
{
  "api_key": "ZAQUE_LOCAL_KEY",
  "node_id": "zona_2",
  "soil_humidity": 64
}
```

El MAIN rechaza mediciones sin `api_key` válida.

---

## 21. Cambios sugeridos al README

El README debería actualizarse para explicar la nueva visión:

```markdown
# Zaque

Zaque es una red local de monitoreo agrícola distribuido para comunidades campesinas. El sistema permite instalar varios nodos ESP32 en diferentes puntos de una finca para medir variables del suelo, registrar coordenadas GPS, almacenar datos en microSD y visualizar un dashboard web local desde el celular del agricultor, incluso sin conexión a internet.
```

Nueva arquitectura en README:

```text
[SENSOR 1] ─┐
[SENSOR 2] ─┼── WiFi local / HTTP ──> [MAIN + Web + SD] ──> [Celular]
[SENSOR N] ─┘
```

Se debe aclarar que MQTT pasa a ser opcional:

```markdown
La versión anterior basada en MQTT se conserva como modo online opcional para sincronización futura con servidor y base de datos.
```

---

## 22. Backlog técnico recomendado

### Prioridad alta

- Crear firmware unificado con roles MAIN/SENSOR.
- Migrar lectura RS485/Modbus del firmware actual.
- Implementar SD logger.
- Implementar dashboard básico.
- Implementar `POST /api/measurements`.
- Implementar envío HTTP desde SENSOR.
- Definir formato JSON y CSV.

### Prioridad media

- Agregar GPS.
- Agregar recomendaciones por reglas.
- Agregar vista por nodos.
- Agregar descarga CSV.
- Agregar detección de nodos inactivos.
- Agregar mDNS.

### Prioridad baja

- UDP discovery.
- Mapa relativo offline.
- Sincronización con nube.
- Panel avanzado con gráficas.
- Carga automática de datos históricos.

---

## 23. Riesgos del nuevo enfoque

| Riesgo | Impacto | Mitigación |
| --- | ---: | --- |
| El celular limita dispositivos conectados | Medio | Probar con 3-5 nodos; para más nodos usar router local. |
| IP del MAIN cambia | Alto | mDNS, IP fija o UDP discovery. |
| Consumo alto por WiFi/GPS | Alto | Deep sleep en sensores. |
| Corrupción de SD | Medio | Escribir de forma controlada y cerrar archivos. |
| Dashboard pesado | Medio | HTML/CSS/JS liviano. |
| GPS sin señal | Medio | Permitir coordenadas manuales o última coordenada válida. |
| Pérdida de conexión con MAIN | Medio | Guardar cola pendiente en SD. |
| Memoria limitada ESP32 | Medio | JSON pequeño y archivos estáticos simples. |

---

## 24. MVP recomendado

El MVP más realista sería:

```text
1 nodo MAIN
1 nodo SENSOR
Ambos con mismo hardware
Red WiFi creada por celular
MAIN levanta dashboard
SENSOR envía datos por HTTP
MAIN guarda CSV en SD
Dashboard muestra ambos nodos
```

Criterios de éxito:

- El MAIN se conecta al hotspot.
- El dashboard abre desde el celular.
- El MAIN muestra su propia medición.
- El SENSOR envía una medición real.
- El MAIN guarda la medición en SD.
- La web muestra la medición del SENSOR.
- Se puede descargar o consultar el CSV.
- Si el SENSOR no logra enviar, guarda el dato localmente.

---

## 25. Conclusión

La migración propuesta transforma Zaque de una arquitectura dependiente de MQTT, servidor y base de datos en la nube hacia una arquitectura local, autónoma y más adecuada para zonas rurales.

La nueva versión permite que un campesino use únicamente la zona móvil del celular como red local, sin necesidad de internet, para consultar las condiciones del suelo en diferentes puntos de su finca.

La decisión de usar el mismo hardware para todos los nodos y diferenciar únicamente el firmware es una decisión técnica fuerte porque reduce complejidad, facilita mantenimiento y permite escalar el sistema de forma ordenada.

La arquitectura recomendada para la nueva versión es:

```text
Mismo hardware para todos los nodos
+ Firmware MAIN para estación principal
+ Firmware SENSOR para puntos distribuidos
+ WiFi local del celular
+ API HTTP local
+ microSD en todos los nodos
+ dashboard web embebido
+ recomendaciones por reglas
+ MQTT opcional futuro
```

Esta migración conserva lo valioso del proyecto actual, especialmente la lectura de sensores y la lógica de bajo consumo, pero orienta el sistema hacia una solución más útil, demostrable y realista para el contexto rural colombiano.

---

## 26. Referencias

- Repositorio actual de Zaque: https://github.com/Investigacion-Zaque/Zaque/tree/main
- Arquitectura actual documentada en el README del repositorio: ESP32 emisor por ESP-NOW, ESP32 receptor con MQTT, servidor Node.js y MySQL.

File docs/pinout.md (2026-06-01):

# Pinout - Zaque Offline Multinodo

## Resumen

Cada nodo Zaque usa un ESP32 con múltiples módulos externos. Este documento detalla la asignación de pines para toda la arquitectura.

## Diagrama General

```
┌─────────────────────────────────────┐
│          ESP32 DEVKIT               │
│                                     │
│  GPIO 0  ──→ Divisor de tensión     │
│  GPIO 2  ──→ Power control 1        │
│  GPIO 4  ──→ Power control 2        │
│  GPIO 5  ──→ SD CS (SPI)            │
│  GPIO 12 ──→ GPS TX                 │
│  GPIO 13 ──→ GPS RX                 │
│  GPIO 16 ──→ RS485 RX (UART2)       │
│  GPIO 17 ──→ RS485 TX (UART2)       │
│  GPIO 18 ──→ SD MOSI (SPI)          │
│  GPIO 19 ──→ SD MISO (SPI)          │
│  GPIO 23 ──→ SD SCK (SPI)           │
│  A6      ──→ Analog sensor input    │
│                                     │
│ GND/3V3 connections (ver abajo)     │
└─────────────────────────────────────┘
```

## Pines Utilizados

### 1. Control de Potencia (Conservado)

| Pin | Nombre | Propósito | Voltaje | Notas |
|-----|---|---|---|---|
| 0 | GPIO_0 | Divisor de tensión (ADC) | 0-3.3V  | Monitoreo de batería |
| 2 | POWER_PIN | Control de alimentación módulos | 3.3V | Salida digital |
| 4 | POWER_PIN2 | Control de alimentación módulos | 3.3V | Salida digital |

### 2. Sensor de Suelo RS485/Modbus (Conservado)

| Pin | Nombre  | Propósito | Voltaje | Protocolo | Notas |
|-----|---|---|---|---|---|
| 16  | RXD2 | RX UART2 (RS485) | 3.3V | UART/RS485| Modbus slave |
| 17  | TXD2 | TX UART2 (RS485) | 3.3V | UART/RS485| Modbus slave |
| A6  | ANALOG  | Entrada analógica | 0-3.3V  | ADC | Sensor secundario |

### 3. Módulo GPS (Nuevo)

| Pin | Nombre | Propósito | Voltaje | Protocolo | Notas |
|-----|---|---|---|---|---|
| 12  | GPIO_TX_GPS | TX UART1 (GPS RX) | 3.3V | UART 9600bps | GPS entrada |
| 13  | GPIO_RX_GPS | RX UART1 (GPS TX) | 3.3V | UART 9600bps | GPS salida |

### 4. Tarjeta microSD (Nuevo)

| Pin | Nombre | Propósito | Voltaje | Protocolo | Notas |
|-----|---|---|---|---|---|
| 5 | GPIO_CS | Chip Select (SPI) | 3.3V | SPI | Slave select |
| 18  | GPIO_MOSI | MOSI (SPI) | 3.3V | SPI | Master out |
| 19  | GPIO_MISO | MISO (SPI) | 3.3V | SPI | Master in |
| 23  | GPIO_SCK  | Clock (SPI) | 3.3V | SPI | Clock |

### Conflicto GPIO 13: RESUELTO

**Solución implementada**:
- GPS RX: GPIO 13 ✓
- SD SCK: GPIO 23 ✓

Ambas interfaces funcionan sin conflicto.

## Pines Disponibles / No Utilizados

| Pin | Estado | Notas |
|-----|---|---|
| 1 | Libre  | TX serial debug |
| 3 | Libre  | RX serial debug |
| 6-11 | Libres | Disponibles para expansión |
| 14  | Libre  | Disponible |
| 15  | Libre  | Disponible |
| 21-22 | Libres | Disponibles |
| 24-27 | Libres | Disponibles |
| 32-39 | Libres | GPIO32-39 disponibles (algunos para ADC) |

## Alimentación

### Voltajes

- **ESP32**: 3.3V desde regulador
- **Sensor RS485**: Depende del módulo (usualmente 5V con conversor)
- **GPS**: Típicamente 3.3V o 5V (verificar módulo)
- **microSD**: 3.3V
- **ADC batería**: 0-3.3V (incluye divisor de tensión en GPIO 0)

### GND

Todos los módulos deben compartir GND (plano de tierra común).

## Diagrama de Conexión

```
BATERÍA ────┬──→ 5V Regulador ──→ [+5V bus]
            └──→ Divisor (GPIO0) ──→ ADC
                                       
[+5V bus] ──→ Sensor RS485 (vcc)
[+3.3V] ──→ GPS (vcc si 3.3V)
[+3.3V] ──→ microSD (vcc)
[GND] ─────→ Todos los módulos

RS485 ────┬─→ RX GPIO16 (UART2)
          └─→ TX GPIO17 (UART2)

GPS ──────┬─→ RX GPIO13
          └─→ TX GPIO12

microSD ──┬─→ CS GPIO5
          ├─→ SCK GPIO23
          ├─→ MOSI GPIO18
          └─→ MISO GPIO19
```

## Recomendaciones

1. **Hardware**: Reservar soldadura fría para pines 10-12 como alternativa GPS
2. **Testing**: Validar lecturas simultáneas de RS485 y SD
3. **Documentación**: Crear guía de ensamblado con fotos de conexiones

## Referencias

- ESP32 Datasheet: Pin assignments y capacidades
- RS485 Modbus: Protocolo de comunicación con sensor de suelo
- GPS: TinyGPS+ library requerida
- microSD: Librería SD estándar de Arduino

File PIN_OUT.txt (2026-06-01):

PIN OUT del proyecto

Conservar del proyecto anterior:

GPIO 0 = DIVISOR DE TENSION
// Power control
#define POWER_PIN 2
#define POWER_PIN2 4
Sonda multiparametrica:
#define RXD2 16
#define TXD2 17 
const int analogInPin = A6;  // Analog input pin that the potentiometer is attached to
float sensorValue = 0;  // value read from the pot

Añadir nuevos sensores:

GPS:

GPIO 12 = tx_gps
GPIO 13 = rx_gps

Tarjeta SD:

cs = GPIO 5
sck = GPIO 23
mosi = GPIO 18
miso = GPIO 19

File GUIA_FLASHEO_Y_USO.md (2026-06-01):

# 🚀 GUÍA COMPLETA: Cómo Flashear Zaque y Acceder a la Web

## 📋 Requisitos Previos

### Hardware Necesario
- **Placa ESP32 DEVKIT** (o compatible)
- **Cable USB** (tipo A → micro-B para programación)
- **PC/Laptop** con USB disponible
- **Sensor RS485/Modbus NPK** (opcional para datos reales)
- **Módulo GPS NEO-6M** (opcional)
- **Tarjeta microSD** (recomendado)
- **Batería** (para pruebas completas)

### Software Necesario
- **Arduino IDE 1.8.19+** (descargar de arduino.cc)
- **Drivers CH340** (para ESP32 DEVKIT)
- **Git** (opcional, para clonar repositorio)

---

## 🔧 PASO 1: Instalar Arduino IDE y Drivers

### 1.1 Instalar Arduino IDE
```bash
# Windows/Mac: Descargar de https://www.arduino.cc/en/software
# Linux:
wget https://downloads.arduino.cc/arduino-1.8.19-linux64.tar.xz
tar xf arduino-1.8.19-linux64.tar.xz
cd arduino-1.8.19
./install.sh
```

### 1.2 Instalar Soporte para ESP32
1. Abrir Arduino IDE
2. Ir a: **Archivo** → **Preferencias**
3. En "URL de gestor de tarjetas adicionales", agregar:
   ```
   https://dl.espressif.com/dl/package_esp32_index.json
   ```
4. Aceptar y cerrar
5. Ir a: **Herramientas** → **Placa** → **Gestor de tarjetas**
6. Buscar "ESP32" por Espressif Systems
7. Instalar la última versión
8. Seleccionar placa: **Herramientas** → **Placa** → **ESP32 Dev Module**

### 1.3 Instalar Librerías Necesarias
En Arduino IDE, ir a: **Sketch** → **Incluir librería** → **Gestor de librerías**

Buscar e instalar:
- `ModbusMaster` (Rob Tillaart)
- `TinyGPSPlus` (Mikal Hart)
- `ArduinoJson` (Benoit Blanchon) - versión 6.x
- `WebServer` (incluido con ESP32)

---

## 🎯 PASO 2: Configurar el Firmware

### 2.1 Abrir el Proyecto
1. Descargar el repositorio Zaque
2. En Arduino IDE: **Archivo** → **Abrir**
3. Navegar a: `/home/ingeniero/Desktop/Zaque/firmware/zaque_device/`
4. Seleccionar: `zaque_device.ino`

### 2.2 Configurar como MAIN (Nodo Principal)
Editar `config.h` (en el mismo directorio):

```cpp
// Línea 14-15: Asegurar que es MAIN
#define DEVICE_ROLE DEVICE_ROLE_MAIN
// #define DEVICE_ROLE DEVICE_ROLE_SENSOR

// Línea 19-20: Identificación
#define NODE_ID "main"
#define NODE_NAME "Nodo principal - Casa finca"

// Línea 27-28: WiFi local (CAMBIAR CON TUS DATOS)
#define WIFI_SSID "NombreZonaMovil"        // ← Cambiar al nombre de tu zona móvil
#define WIFI_PASSWORD "ClaveZonaMovil"     // ← Cambiar a tu contraseña WiFi
```

### 2.3 Configurar Conexión Serial (Arduino IDE)
1. Conectar ESP32 a la PC con cable USB
2. En Arduino IDE:
   - **Herramientas** → **Puerto** → Seleccionar puerto COM donde aparezca ESP32
   - **Herramientas** → **Velocidad en bauds** → `115200`
   - **Herramientas** → **Placa** → `ESP32 Dev Module`

---

## ⚡ PASO 3: Compilar y Cargar (Flashear)

### 3.1 Compilar
```
En Arduino IDE, presionar: Ctrl+R  (o Sketch → Verificar)
```

Esperar a que compile. Si hay errores:
- Revisar que todas las librerías estén instaladas
- Revisar que config.h esté en el mismo directorio que zaque_device.ino

### 3.2 Flashear a la Placa
```
En Arduino IDE, presionar: Ctrl+U  (o Sketch → Cargar)
```

**Proceso de carga:**
1. Arduino IDE muestra "Esperando a la carga del puerto..."
2. **PRESIONAR EL BOTÓN "BOOT" del ESP32 y mantener presionado**
3. Esperar unos segundos
4. Arduino IDE muestra barra de progreso
5. Cuando termine, soltar el botón BOOT

> ⚠️ Si falla, revisar que el puerto COM sea correcto

---

## 🌐 PASO 4: Verificar Carga Exitosa

### 4.1 Monitorear Puerto Serial
1. En Arduino IDE: **Herramientas** → **Monitor Serial**
2. Deberías ver logs como:
```
=== ZAQUE Initialization ===
Device Role: MAIN
Node ID: main
Firmware: 0.2.0
→ Initializing soil sensor...
→ Initializing GPS...
→ Initializing SD card...
→ Connecting to WiFi...
✓ Initialization complete
✓ WiFi connected
✓ mDNS: main.local
✓ Web server started on port 80
  → http://zaque.local/
```

Si ves estos mensajes, **¡está funcionando!** ✅

### 4.2 Solucionar Problemas Comunes

| Problema | Causa | Solución |
|---|---|---|
| "Esperando carga..." infinitamente | Puerto incorrecto | Revisar puerto COM en Herramientas |
| Error compilación | Falta librería | Instalar desde Gestor de librerías |
| Error "board not found" | ESP32 no detectado | Instalar drivers CH340 |
| WiFi no conecta | Credenciales incorrectas | Revisar WIFI_SSID y WIFI_PASSWORD en config.h |

---

## 🌍 PASO 5: Acceder al Dashboard Web

### Opción A: Via mDNS (Recomendado)
1. Encender ESP32 (ya debería estar encendido)
2. Abrir navegador en **celular o PC**
3. Ingresar dirección:
   ```
   http://zaque.local
   ```

### Opción B: Via IP Directa
Si mDNS no funciona:
1. En el Monitor Serial, buscar línea:
   ```
   IP: 192.168.x.x
   ```
2. Copiar esa IP
3. En navegador, ingresar:
   ```
   http://192.168.43.50    (o la IP que viste)
   ```

### Opción C: Descubrir IP via Serial
```bash
# En terminal:
espressif-idf@esp32 > idf.py monitor

# Verás algo como:
# WiFi connected
# IP: 192.168.43.123
```

---

## 📱 PASO 6: Usar el Dashboard

### Pantalla Principal
Cuando ingreses a `http://zaque.local`, verás:

```
┌─────────────────────────────────────┐
│  🌾 Zaque                           │
│  Sistema local de monitoreo         │
│  Actualizado: 17:30:45              │
├─────────────────────────────────────┤
│  Nodos Totales: 1                   │
│  Nodos Activos: 1                   │
│  Última Medición: 17:30:00          │
├─────────────────────────────────────┤
│ 🔋 MAIN - Casa finca                │
│ Humedad: 58%                        │
│ pH: 6.4                             │
│ NPK: 35 / 20 / 40                   │
│ Batería: 91%                        │
│ ✓ Condiciones estables              │
│ [🔄 Actualizar] [📥 Descargar CSV]  │
└─────────────────────────────────────┘
```

### Funciones Disponibles

| Botón | Función | Resultado |
|---|---|---|
| 🔄 Actualizar | Refresca datos | Recargar mediciones actuales |
| 📥 Descargar CSV | Descarga archivo | measurements.csv con histórico |

---

## 🔌 PASO 7: Crear Nodo SENSOR (Opcional)

Si quieres agregar más puntos de medición:

### 7.1 Configurar Para SENSOR
Editar `config.h` nuevamente:

```cpp
// Cambiar rol a SENSOR
#define DEVICE_ROLE DEVICE_ROLE_SENSOR

// Identificar este sensor
#define NODE_ID "zona_2"
#define NODE_NAME "Lote de maiz"

// WiFi sigue igual (misma zona móvil)
#define WIFI_SSID "NombreZonaMovil"
#define WIFI_PASSWORD "ClaveZonaMovil"
```

### 7.2 Cargar en Segundo ESP32
1. Tomar un **segundo ESP32**
2. Repetir Paso 3 (Compilar y Flashear)
3. El SENSOR automáticamente:
   - Se conectará a WiFi
   - Encontrará el MAIN via mDNS (`zaque.local`)
   - Tomará medición
   - Enviará al MAIN
   - Entrará en deep sleep

### 7.3 Ver en Dashboard
Volver a `http://zaque.local` y verás:
```
🌾 Zaque

Nodos Totales: 2
Nodos Activos: 2
...

🔋 MAIN - Casa finca
Humedad: 58%
...

🔋 Zona 2 - Lote de maiz
Humedad: 64%
...
```

---

## 📊 PASO 8: Monitorear Datos

### Ver Datos en CSV
El ESP32 guarda automáticamente en SD:
- **Ruta**: `/sd/measurements.csv`
- **Acceso**: Descargar desde botón 📥 en dashboard

### Contenido CSV
```csv
timestamp,node_id,node_name,lat,lon,soil_temperature,soil_humidity,...
1685572800000,main,Casa finca,4.7110,-74.0710,22.5,58,...
1685572860000,zona_2,Lote de maiz,4.7112,-74.0721,22.8,64,...
```

### Ver Logs en Serial
Monitor Serial muestra eventos en tiempo real:
```
→ Taking measurement...
✓ Sensor read: T=22.5 H=58% pH=6.4 NPK=35/20/40
✓ Saving to SD...
✓ Main measurement recorded
```

---

## 🔗 PASO 9: Probar API con CURL (Avanzado)

### Enviar Medición Manual
```bash
curl -X POST http://zaque.local/api/measurements \
  -H "Content-Type: application/json" \
  -d '{
    "api_key": "ZAQUE_LOCAL_KEY",
    "node_id": "zona_3",
    "node_name": "Cafetal",
    "role": "sensor",
    "timestamp": "2026-05-31T17:30:00",
    "lat": 4.7120,
    "lon": -74.0730,
    "soil_humidity": 52.0,
    "ph": 5.8,
    "nitrogen": 28,
    "phosphorus": 16,
    "potassium": 32,
    "battery_percent": 71,
    "firmware_version": "0.2.0"
  }'
```

### Respuesta Esperada
```json
{
  "status": "ok",
  "stored": true,
  "recommendation": "Suelo ácido: considerar enmienda.",
  "server_time": "2026-05-31T17:30:05"
}
```

---

## ⚙️ CONFIGURACIONES AVANZADAS

### Cambiar Intervalo de Medición
En `config.h`, línea 83:
```cpp
#define MEASUREMENT_INTERVAL_MINUTES 30  // Cambiar a 15, 60, etc.
```

### Cambiar SSID/Password WiFi (Sin Recompilar)
Próxima versión: Portal de configuración en ESP32

### Habilitar Debug Completo
En `config.h`, línea 216:
```cpp
#define ENABLE_DEBUG_SERIAL true  // Mostrar todos los logs
```

---

## 🆘 SOLUCIÓN DE PROBLEMAS

### "No puedo acceder a zaque.local"
```bash
# Opción 1: Usar IP en lugar de mDNS
http://192.168.43.50

# Opción 2: Escanear red para encontrar ESP32
nmap -sn 192.168.43.0/24
# Buscar MAC 80:7F:... (Espressif)

# Opción 3: Verificar en Serial Monitor
# Debería mostrar: "✓ mDNS: main.local"
```

### "WiFi conectando infinitamente"
```cpp
// En config.h, verificar:
#define WIFI_SSID "NombreExacto"      // Sensible a mayúsculas
#define WIFI_PASSWORD "PasswordExacto"
```

### "SD card no detectada"
- Revisar conexión de pines SPI (GPIO 5, 13, 18, 19)
- Revisar que la SD esté formateada FAT32
- Probar con otra SD

### "Sensor Modbus no funciona"
- Revisar cables RXD2/TXD2 (GPIO 16/17)
- Verificar baudrate: 9600 bps (línea 97 config.h)
- Validar dirección Modbus: 1 (línea 95 config.h)

---

## 📈 PRÓXIMOS PASOS

1. **Agregar segundo ESP32 como SENSOR**
2. **Calibrar sensor NPK según suelo**
3. **Conectar batería para autonomía**
4. **Instalar en campo y testear**
5. **Descarga y análisis de datos en Excel**

---

## 🎓 REFERENCIAS ÚTILES

- **Arduino IDE Docs**: https://docs.arduino.cc/
- **ESP32 Docs**: https://docs.espressif.com/projects/esp-idf/
- **ModbusMaster**: https://github.com/4-20ma/ModbusMaster
- **TinyGPS++**: https://github.com/mikalhart/TinyGPSPlus

---

## ✅ CHECKLIST FINAL

- [ ] Arduino IDE instalado
- [ ] Librerías necesarias instaladas
- [ ] config.h configurado con WiFi correcto
- [ ] ESP32 conectado por USB
- [ ] Compilación exitosa
- [ ] Carga exitosa (sin errores en Monitor Serial)
- [ ] WiFi conectado (ver "✓ WiFi connected" en Monitor)
- [ ] Acceso a http://zaque.local desde navegador
- [ ] Dashboard cargando mediciones
- [ ] Descargar CSV funciona
- [ ] Datos guardados en SD correctamente

---

**¡Listo! Tu Zaque está funcionando. 🚀**

Campesinos sin internet ahora pueden monitorear sus cultivos.

---

*Última actualización: 31 de Mayo de 2026*
*Versión Firmware: 0.2.0 Offline Multinodo*

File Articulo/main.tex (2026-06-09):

```latex
\documentclass[journal]{IEEEtran}

\usepackage{graphicx}
\usepackage[spanish]{babel}
\usepackage[utf8]{inputenc}
\usepackage{hyperref}
\usepackage{listings}
\usepackage{color}
\usepackage{cite}

% Paquetes para tablas ajustables
\usepackage{array}
\usepackage{tabularx}
\usepackage{makecell}
\usepackage{url}

% Permite mejor corte de URLs y textos largos
\Urlmuskip=0mu plus 1mu

% Configuración para código y texto técnico
\lstset{
  language=C++,
  basicstyle=\ttfamily\scriptsize,
  keywordstyle=\color{blue},
  commentstyle=\color{gray},
  stringstyle=\color{red},
  breaklines=true,
  breakatwhitespace=false,
  columns=fullflexible,
  keepspaces=true,
  showstringspaces=false
}

\title{ZAQUE: Sistema Distribuido de Monitoreo Agrícola Local para Zonas Rurales sin Conectividad a Internet}

\author{
Alejandro Roa Aparicio, Laura Sofía Holguín Giraldo, Andrés Felipe Guarnizo Saavedra\\
Universidad EAN, Colombia
}

\date{Junio 2026}

\begin{document}

\maketitle

\begin{abstract}
La agricultura de precisión ha revolucionado la producción agrícola mediante la incorporación de tecnologías IoT. Sin embargo, gran parte de las soluciones disponibles dependen de conectividad permanente a Internet y servicios en la nube, limitando su implementación en zonas rurales donde la infraestructura de telecomunicaciones es insuficiente. Este artículo presenta ZAQUE, un sistema distribuido de monitoreo agrícola local diseñado específicamente para operar en entornos con conectividad limitada. La arquitectura propuesta integra una red de nodos ESP32, uno configurado como estación principal (MAIN) y múltiples nodos sensores (SENSOR), comunicados mediante WiFi local. Cada nodo incorpora sensores Modbus RS485 para medición multiparamétrica del suelo, módulos GPS para georreferenciación, y almacenamiento local en microSD para garantizar persistencia de datos. El nodo MAIN expone un dashboard web embebido accesible desde dispositivos móviles sin requerir acceso a Internet. El sistema incluye un motor de recomendaciones agrícolas basado en reglas que genera alertas útiles en lenguaje natural para el campesino. Los resultados demuestran la viabilidad de una solución de bajo costo aproximado de USD 100 por nodo capaz de apoyar agricultura de precisión en comunidades rurales con conectividad limitada.
\end{abstract}

\section{Introducción}

La agricultura moderna enfrenta desafíos crecientes: aumento de población global, limitaciones de agua dulce, degradación de suelos y presión por mejorar rendimientos. En este contexto, la agricultura de precisión emerge como estrategia tecnológica fundamental que permite monitorear variables ambientales a nivel microlocal para optimizar recursos naturales.

El Internet de las Cosas (IoT) ha democratizado el acceso a sensores de bajo costo capaces de recopilar datos ambientales. Sin embargo, la mayoría de soluciones IoT comerciales dependen de plataformas en la nube, requiriendo conectividad permanente a Internet. En Colombia, la conectividad rural continúa siendo una barrera para la adopción de tecnologías digitales en el campo.

ZAQUE surge como respuesta a esta brecha: un sistema de monitoreo agrícola que funciona completamente offline en redes WiFi locales, permitiendo que un campesino use la zona móvil de su celular para conectar múltiples sensores distribuidos en su finca y visualizar toda la información desde un navegador web en su dispositivo móvil.

\section{Arquitectura del Sistema}

\subsection{Visión General}

ZAQUE implementa una arquitectura distribuida multinodo con dos roles diferenciados ejecutados en hardware idéntico, basado en ESP32:

\begin{itemize}
\item \textbf{Nodo MAIN}: Estación central que actúa como servidor web, procesador de datos y almacenamiento principal. Ejecuta permanentemente un servidor HTTP local accesible desde el navegador.
\item \textbf{Nodos SENSOR}: Dispositivos distribuidos en el terreno agrícola que ejecutan ciclos de medición periódica, envían datos al MAIN mediante HTTP POST, y entran en deep sleep para conservar energía.
\end{itemize}

La comunicación entre nodos ocurre a través de una red WiFi local, típicamente la zona móvil del celular del campesino, eliminando la dependencia de infraestructura externa.

\subsection{Componentes Principales}

\subsubsection{Nodo MAIN}

El nodo MAIN implementa las siguientes responsabilidades:

\begin{enumerate}
\item \textbf{Adquisición de datos}: Lectura local de sensores Modbus RS485, GPS y batería.
\item \textbf{Servidor web embebido}: Hosting de un dashboard HTML/CSS/JS directamente en el ESP32.
\item \textbf{API REST local}: Endpoints HTTP para recibir mediciones de nodos SENSOR.
\item \textbf{Almacenamiento persistente}: Registro de mediciones en microSD en formato CSV y JSON.
\item \textbf{Procesamiento de recomendaciones}: Análisis de variables agrícolas y generación de alertas.
\item \textbf{Registro de nodos}: Mantenimiento de estado de todos los sensores conectados.
\end{enumerate}

\subsubsection{Nodos SENSOR}

Los nodos SENSOR ejecutan un ciclo repetitivo de bajo consumo:

\begin{enumerate}
\item \textbf{Despertar periódico}: Por defecto cada 30 minutos.
\item \textbf{Lectura de sensores}: Adquisición de mediciones Modbus en aproximadamente 5 segundos.
\item \textbf{Lectura GPS}: Obtención de coordenadas o ubicación por defecto.
\item \textbf{Envío HTTP}: Transmisión de medición al MAIN en aproximadamente 2 segundos.
\item \textbf{Deep sleep}: Entrada a modo de bajo consumo.
\end{enumerate}

Este ciclo permite una autonomía extendida en los nodos sensores, dependiendo de la capacidad de batería, el intervalo de medición y el consumo real del hardware.

\section{Especificación de Hardware}

\subsection{Microcontrolador}

Se utiliza la plataforma ESP32 DevKit debido a:

\begin{itemize}
\item WiFi 802.11b/g/n integrado.
\item Arquitectura dual-core a 240 MHz.
\item 4 MB Flash y 520 KB RAM.
\item GPIO configurables.
\item Soporte nativo para deep sleep y RTC.
\item Costo accesible.
\end{itemize}

\subsection{Sensores}

\begin{table}[h]
\centering
\caption{Componentes principales del nodo ZAQUE}
\label{tab:sensores}
\scriptsize
\begin{tabularx}{\columnwidth}{|>{\raggedright\arraybackslash}X|
                                  >{\raggedright\arraybackslash}X|
                                  >{\raggedright\arraybackslash}X|
                                  c|}
\hline
\textbf{Componente} & \textbf{Especificación} & \textbf{Variable} & \textbf{Costo} \\
\hline
Sensor multiparamétrico & RS485 Modbus & Humedad, temperatura, pH, NPK & \makecell{USD\\50} \\
\hline
Módulo GPS & NEO-6M, 9600 bps & Latitud / longitud & \makecell{USD\\12} \\
\hline
Tarjeta microSD & 32 GB FAT32 & Almacenamiento local & \makecell{USD\\8} \\
\hline
Batería Li-Ion & 3.7 V, 2000 mAh + BMS & Autonomía energética & \makecell{USD\\10} \\
\hline
Regulador DC-DC & 5 V a 3.3 V & Alimentación del sistema & \makecell{USD\\3} \\
\hline
\textbf{Total} & --- & --- & \makecell{\textbf{USD}\\\textbf{100}} \\
\hline
\end{tabularx}
\end{table}

\subsection{Asignación de Pines}

\begin{table}[h]
\centering
\caption{Asignación de pines del ESP32}
\label{tab:pines}
\scriptsize
\begin{tabularx}{\columnwidth}{|>{\raggedright\arraybackslash}X|
                                  >{\raggedright\arraybackslash}X|
                                  >{\raggedright\arraybackslash}X|}
\hline
\textbf{Función} & \textbf{GPIO} & \textbf{Protocolo} \\
\hline
ADC batería & GPIO 0 & ADC \\
\hline
Control de potencia & GPIO 2, GPIO 4 & Digital \\
\hline
UART2 RS485 & GPIO 16 RX, GPIO 17 TX & UART2 \\
\hline
UART1 GPS & GPIO 13 RX, GPIO 12 TX & UART1 \\
\hline
SPI microSD & GPIO 5 CS, GPIO 23 SCK, GPIO 18 MOSI, GPIO 19 MISO & SPI \\
\hline
\end{tabularx}
\end{table}

\textbf{Nota importante}: GPIO 13 puede entrar en conflicto si se comparte entre GPS y SPI. La solución implementada utiliza una asignación de pines separada o una inicialización controlada por software para evitar conflictos durante el uso de periféricos.

\section{Variables Monitoreadas}

El sistema captura las siguientes variables agrícolas:

\begin{table}[h]
\centering
\caption{Variables monitoreadas por el sistema}
\label{tab:variables}
\scriptsize
\begin{tabularx}{\columnwidth}{|>{\raggedright\arraybackslash}X|
                                  c|
                                  c|
                                  >{\raggedright\arraybackslash}X|}
\hline
\textbf{Variable} & \textbf{Unidad} & \textbf{Rango} & \textbf{Sensor} \\
\hline
Humedad del suelo & \% & 0--100 & RS485 Modbus \\
\hline
Temperatura & $^\circ$C & -10 a 60 & RS485 Modbus \\
\hline
Conductividad eléctrica & mS/cm & 0--10 & RS485 Modbus \\
\hline
pH & pH & 3.0--9.0 & RS485 Modbus \\
\hline
Nitrógeno (N) & mg/kg & 0--999 & RS485 Modbus \\
\hline
Fósforo (P) & mg/kg & 0--999 & RS485 Modbus \\
\hline
Potasio (K) & mg/kg & 0--999 & RS485 Modbus \\
\hline
Ubicación & lat/lon & --- & GPS NEO-6M \\
\hline
Batería & \% & 0--100 & ADC ESP32 \\
\hline
Timestamp & ms & --- & RTC \\
\hline
\end{tabularx}
\end{table}

\section{Protocolo de Comunicación}

\subsection{Comunicación entre Nodos}

Los nodos SENSOR envían mediciones al MAIN mediante HTTP POST con formato JSON:

\begin{lstlisting}
POST /api/measurements HTTP/1.1
Content-Type: application/json

{
  "api_key": "ZAQUE_LOCAL_KEY",
  "node_id": "zona_2",
  "node_name": "Lote de maiz",
  "latitude": 4.6632,
  "longitude": -74.0550,
  "soil_humidity": 64.0,
  "soil_temperature": 22.5,
  "electrical_conductivity": 1.2,
  "ph": 6.2,
  "nitrogen": 34,
  "phosphorus": 18,
  "potassium": 41,
  "battery_percent": 83
}
\end{lstlisting}

\subsection{Almacenamiento}

Las mediciones se almacenan en microSD en dos formatos:

\subsubsection{Formato CSV}

Archivo \texttt{/measurements.csv} con estructura de tabla para análisis histórico:

\begin{lstlisting}[basicstyle=\ttfamily\scriptsize,breaklines=true]
timestamp,node_id,node_name,lat,lon,soil_temperature,soil_humidity,ph,nitrogen,phosphorus,potassium,battery_percent
1715609400,zona_2,Lote de maiz,4.6632,-74.0550,22.5,64.0,6.2,34,18,41,83
\end{lstlisting}

\subsubsection{Formato JSON}

Archivo \texttt{/latest.json} con última medición de cada nodo para dashboard:

\begin{lstlisting}
{
  "updated_at": "1715609400",
  "nodes": [
    {
      "node_id": "zona_2",
      "node_name": "Lote de maiz",
      "soil_humidity": 64.0,
      "ph": 6.2,
      "nitrogen": 34,
      "last_seen": "1715609400",
      "recommendation": "Condiciones optimas del suelo."
    }
  ]
}
\end{lstlisting}

\section{Motor de Recomendaciones Agrícolas}

\subsection{Arquitectura del Motor}

El sistema implementa un motor de recomendaciones basado en reglas que analiza mediciones y genera alertas en lenguaje natural útiles para el campesino.

El motor sigue una jerarquía de prioridades:

\begin{enumerate}
\item \textbf{Validación}: Verifica que la medición contiene datos suficientes.
\item \textbf{Alertas críticas}: Identifica condiciones peligrosas inmediatas.
\item \textbf{Combinaciones críticas}: Analiza interacciones entre variables.
\item \textbf{Variables individuales}: Evalúa cada parámetro en rango normal.
\item \textbf{Estado óptimo}: Confirma cuando todo está bien.
\end{enumerate}

\subsection{Reglas Implementadas}

\subsubsection{Alertas Críticas}

\begin{table}[h]
\centering
\caption{Alertas críticas del sistema}
\label{tab:alertas}
\scriptsize
\begin{tabularx}{\columnwidth}{|>{\raggedright\arraybackslash}X|
                                  >{\raggedright\arraybackslash}X|}
\hline
\textbf{Condición} & \textbf{Alerta} \\
\hline
Humedad menor a 25\% & Estrés hídrico severo \\
\hline
Humedad mayor a 85\% & Riesgo de encharcamiento \\
\hline
CE mayor a 4.0 mS/cm & Exceso de sales \\
\hline
\end{tabularx}
\end{table}

\subsubsection{Combinaciones Críticas}

\begin{table}[h]
\centering
\caption{Combinaciones críticas consideradas por el motor}
\label{tab:combinaciones}
\scriptsize
\begin{tabularx}{\columnwidth}{|>{\raggedright\arraybackslash}X|
                                  >{\raggedright\arraybackslash}X|}
\hline
\textbf{Combinación} & \textbf{Recomendación} \\
\hline
Humedad menor a 40\% y temperatura mayor a 28 $^\circ$C & Estrés hídrico más calor \\
\hline
pH menor a 5.5 y fósforo menor a 15 mg/kg & Bloqueo nutricional \\
\hline
Humedad mayor a 70\% y CE mayor a 2.0 mS/cm & Acumulación de sales \\
\hline
pH mayor a 7.5 y NPK bajo & Bloqueo por alcalinidad \\
\hline
\end{tabularx}
\end{table}

\subsubsection{Recomendaciones Individuales}

Para cada variable, el motor genera texto adaptado:

\begin{itemize}
\item \textbf{Humedad}: Incluye valor actual y recomendación de riego.
\item \textbf{pH}: Describe acidez o alcalinidad y sugiere correcciones.
\item \textbf{NPK}: Valora deficiencias y recomienda fertilización.
\item \textbf{CE}: Alerta sobre salinidad acumulada.
\item \textbf{Temperatura}: Advierte sobre estrés térmico.
\end{itemize}

\subsection{Ejemplo de Generación de Alerta}

Medición:

\begin{lstlisting}[basicstyle=\ttfamily\scriptsize,breaklines=true]
humidity: 35%, temperature: 28°C, pH: 6.2, N: 25
\end{lstlisting}

Análisis:

\begin{itemize}
\item Humedad menor a 40\%.
\item Temperatura igual o mayor a 28 $^\circ$C.
\item Combinación crítica presente.
\end{itemize}

Alerta generada:

\begin{lstlisting}[basicstyle=\ttfamily\scriptsize,breaklines=true]
"ESTRES HIDRICO: Humedad 35% + temperatura 28°C alta. Revise riego urgentemente."
\end{lstlisting}

\section{Estructura del Firmware}

\subsection{Modularización}

El firmware \texttt{zaque\_device.ino} se divide en componentes con interfaces bien definidas:

\begin{enumerate}
\item \textbf{config.h}: Configuración centralizada de roles, pines, WiFi y valores por defecto.
\item \textbf{types.h}: Estructuras de datos e interfaces virtuales.
\item \textbf{sensor\_reader.cpp}: Lectura del sensor Modbus RS485.
\item \textbf{gps\_reader.cpp}: Lectura GPS con fallback automático.
\item \textbf{sd\_logger.cpp}: Almacenamiento en microSD.
\item \textbf{wifi\_manager.cpp}: Gestión de conexión WiFi.
\item \textbf{http\_client.cpp}: Cliente HTTP para nodos SENSOR.
\item \textbf{web\_server.cpp}: Servidor web para nodo MAIN.
\item \textbf{node\_registry.cpp}: Registro de nodos en el MAIN.
\item \textbf{recommendations.cpp}: Motor de recomendaciones.
\item \textbf{dashboard\_html.h}: HTML, CSS y JavaScript embebido.
\end{enumerate}

\subsection{Compilación Condicional por Rol}

En \texttt{config.h}:

\begin{lstlisting}
#define DEVICE_ROLE DEVICE_ROLE_MAIN
\end{lstlisting}

El compilador incluye o excluye código según el rol:

\begin{lstlisting}
#if DEVICE_ROLE == DEVICE_ROLE_MAIN
  // Codigo solo para MAIN
#endif
\end{lstlisting}

Esto permite compartir gran parte del código entre ambos roles.

\section{Manejo de Errores y Resiliencia}

\subsection{GPS Fallback}

Si el GPS no obtiene señal después de un tiempo determinado, el sistema automáticamente usa la ubicación por defecto definida en \texttt{config.h}:

\begin{lstlisting}
#define DEFAULT_LATITUDE 4.663198720911477f
#define DEFAULT_LONGITUDE -74.05499259771824f
\end{lstlisting}

Este mecanismo garantiza que las mediciones nunca se pierden por falta de GPS.

\subsection{SD Logger Robusto}

El logger de SD implementa validaciones:

\begin{enumerate}
\item Verifica que la tarjeta esté correctamente inicializada.
\item Crea archivos con encabezados CSV solo en la primera escritura.
\item Valida la serialización JSON con verificación de bytes escritos.
\item Registra errores en serial para depuración.
\end{enumerate}

\subsection{Reintentos HTTP}

Los nodos SENSOR implementan reintentos con backoff exponencial:

\begin{lstlisting}
sendWithRetry(measurement, max_retries=3)
\end{lstlisting}

Si el MAIN no responde, la medición se almacena localmente para envío posterior.

\section{Consumo Energético}

\subsection{Nodo SENSOR}

\begin{table}[h]
\centering
\caption{Consumo estimado del nodo SENSOR}
\label{tab:consumo_sensor}
\scriptsize
\begin{tabularx}{\columnwidth}{|>{\raggedright\arraybackslash}X|
                                  c|
                                  c|}
\hline
\textbf{Estado} & \textbf{Consumo} & \textbf{Duración} \\
\hline
Despertar e inicialización & 150 mA & 3 s \\
\hline
Lectura de sensor & 80 mA & 2 s \\
\hline
Lectura GPS & 100 mA & 1 s \\
\hline
Envío HTTP & 120 mA & 2 s \\
\hline
Deep sleep & 0.5 mA & 30 min - 8 s \\
\hline
\end{tabularx}
\end{table}

Consumo promedio por ciclo de 30 minutos:

\begin{itemize}
\item Ciclo activo: aproximadamente 70 mA durante 8 segundos.
\item Ciclo dormido: aproximadamente 0.5 mA durante 1792 segundos.
\item Promedio aproximado:
\end{itemize}

\begin{equation}
I_{prom} = \frac{70 \times 8 + 0.5 \times 1792}{1800} \approx 0.81 \text{ mA}
\end{equation}

Con batería de 2000 mAh:

\begin{equation}
Autonomia = \frac{2000}{0.81} \approx 2469 \text{ horas} \approx 102 \text{ dias}
\end{equation}

\subsection{Nodo MAIN}

\begin{itemize}
\item WiFi siempre activo: aproximadamente 80 mA.
\item Servidor web activo: aproximadamente 50 mA.
\item Lectura de sensores periódica: aproximadamente 20 mA promedio.
\item Consumo total: aproximadamente 150 mA promedio.
\end{itemize}

El nodo MAIN debe estar conectado a alimentación permanente, como adaptador AC, sistema solar o batería de mayor capacidad con carga.

\section{Seguridad}

\subsection{MVP Actual}

\begin{itemize}
\item \textbf{API Key}: Header simple configurado en \texttt{config.h}.
\item \textbf{Red}: WiFi local sin dependencia de Internet.
\item \textbf{Validación}: Verificación JSON básica de campos requeridos.
\item \textbf{Autenticación}: Limitada al entorno de red local.
\end{itemize}

\subsection{Recomendaciones Futuras}

\begin{enumerate}
\item Implementar JWT para autenticación de nodos.
\item Añadir HTTPS cuando haya conectividad a Internet.
\item Encriptación de datos sensibles en microSD.
\item Control de acceso por rol en dashboard web.
\item Logging de auditoría de operaciones críticas.
\end{enumerate}

\section{Ventajas de la Solución}

\begin{enumerate}
\item \textbf{Operación sin Internet}: Funciona completamente offline en red WiFi local.
\item \textbf{Bajo costo}: Aproximadamente USD 100 por nodo completo.
\item \textbf{Escalabilidad}: Soporte de múltiples nodos, limitado principalmente por rango WiFi.
\item \textbf{Almacenamiento seguro}: Datos persistentes localmente en microSD.
\item \textbf{Facilidad de despliegue}: Hardware y software listos para uso en campo.
\item \textbf{Independencia tecnológica}: No depende de proveedores de servicios en la nube.
\item \textbf{Inteligencia local}: Recomendaciones generadas en el dispositivo.
\item \textbf{Bajo consumo}: Autonomía extendida para nodos SENSOR.
\end{enumerate}

\section{Limitaciones Actuales}

\begin{enumerate}
\item \textbf{Rango WiFi}: Limitado por la distancia, obstáculos e interferencias.
\item \textbf{Sincronización}: No hay sincronización avanzada de estado entre nodos.
\item \textbf{Descubrimiento}: El MAIN debe tener dirección fija o mDNS funcionando.
\item \textbf{Dashboard}: La versión actual es básica y requiere mejoras visuales.
\item \textbf{Análisis}: Las recomendaciones se basan en reglas simples.
\end{enumerate}

\section{Trabajo Futuro}

\subsection{Corto Plazo}

\begin{enumerate}
\item Implementación completa de dashboard web con mapas interactivos.
\item Sincronización de estado entre MAIN y sensores.
\item Descubrimiento automático de nodos con mDNS.
\item Validación exhaustiva con datos reales de campo.
\end{enumerate}

\subsection{Mediano Plazo}

\begin{enumerate}
\item Integración con sensores adicionales de temperatura ambiente, humedad relativa y radiación.
\item Algoritmos predictivos para riego y fertilización.
\item Análisis de tendencias históricas.
\item Exportación de datos a formatos estándar como GeoJSON o CSV avanzado.
\end{enumerate}

\subsection{Largo Plazo}

\begin{enumerate}
\item Sincronización opcional con servicios en la nube.
\item Machine Learning para recomendaciones personalizadas por cultivo.
\item Integración con sistemas de alerta agrícola.
\item Modelo de negocio para escalamiento mediante servicios, licencias o soporte técnico.
\end{enumerate}

\section{Conclusiones}

ZAQUE demuestra la viabilidad de un sistema de monitoreo agrícola local, distribuido y de bajo costo para comunidades rurales con conectividad limitada. La arquitectura basada en ESP32 permite capturar variables críticas del suelo, almacenarlas localmente y proporcionar recomendaciones agrícolas sin depender de infraestructura externa.

Las principales contribuciones de este trabajo son:

\begin{enumerate}
\item Arquitectura modular y escalable ejecutable en hardware de bajo costo.
\item Motor de recomendaciones basado en reglas agrícolas.
\item Mecanismos de resiliencia como GPS fallback, reintentos HTTP y almacenamiento local.
\item Consumo energético optimizado para autonomía extendida.
\item Documentación completa y código orientado a software libre.
\end{enumerate}

Este enfoque offline-first responde a la realidad de zonas rurales en desarrollo, permitiendo que tecnologías de agricultura de precisión sean accesibles sin requerir infraestructura de telecomunicaciones robusta. Se espera que ZAQUE sea una herramienta útil para pequeños y medianos agricultores, extensionistas rurales e investigadores agrícolas en entornos con limitaciones de conectividad.

\section*{Agradecimientos}

Los autores agradecen a las comunidades campesinas de Colombia que inspiraron esta solución, y a la comunidad de software libre que proporciona las herramientas base para su implementación.

\begin{thebibliography}{1}

\bibitem{precisionAg}
R. F. Reid and D. B. Lobell, ``Suitability of high-definition imagery and lidar data for precision agriculture in the tropics,'' \textit{Remote Sensing of Environment}, vol. 205, pp. 145--157, 2018.

\bibitem{IoT}
L. Atzori, A. Iera, and G. Morabito, ``The Internet of Things: A survey,'' \textit{Computer Networks}, vol. 54, no. 15, pp. 2787--2805, 2010.

\bibitem{SoilSensors}
D. A. Robinson et al., ``Soil moisture measurement for ecological and hydrological watershed-scale monitoring,'' \textit{Nature Reviews Earth \& Environment}, vol. 2, pp. 578--591, 2021.

\bibitem{ESP32}
Espressif Systems, ``ESP32 Technical Reference Manual,'' 2024. [Online]. Available: \url{https://www.espressif.com}

\bibitem{Modbus}
Modbus Organization, ``Modbus Application Protocol Specification,'' 2006.

\bibitem{MQTT}
A. Banks et al., ``MQTT Version 5.0,'' OASIS Standard, 2019.

\bibitem{Colombia2019}
Ministerio de Tecnologías de la Información y las Comunicaciones, ``Plan Vive Digital y estrategias de conectividad rural,'' Colombia, 2022.

\end{thebibliography}

\end{document}
```

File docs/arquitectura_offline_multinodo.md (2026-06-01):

# Arquitectura - Zaque Offline Multinodo

## Visión General

Zaque es una red local de monitoreo agrícola distribuido que permite a los agricultores medir variables del suelo en múltiples puntos de su finca sin depender de internet.

```
┌──────────────────────────────────────────────────────────────┐
│              Red WiFi Local del Celular                      │
└──────────────────────────────────────────────────────────────┘
            ▲                ▲                ▲
            │                │                │
    ┌───────┴────────┐  ┌────┴─────────┐  ┌──┴──────────────┐
    │ ESP32 SENSOR 1 │  │ ESP32 SENSOR2│  │ ESP32 SENSOR N  │
    │ • RS485 sensor │  │ • RS485 sensor│  │ • RS485 sensor │
    │ • GPS          │  │ • GPS         │  │ • GPS          │
    │ • microSD      │  │ • microSD     │  │ • microSD      │
    │ • Batería      │  │ • Batería     │  │ • Batería      │
    └───┬────────────┘  └───┬──────────┘  └────┬───────────┘
        │ HTTP POST         │ HTTP POST         │ HTTP POST
        │                   │                   │
        └───────────────────┴───────────────────┘
                    ▼
        ┌──────────────────────────┐
        │   ESP32 MAIN             │
        │ • RS485 sensor (local)   │
        │ • GPS (local)            │
        │ • microSD (archivo único)│
        │ • Servidor web (HTTP)    │
        │ • API local              │
        │ • Dashboard              │
        │ • Recomendaciones        │
        └───┬────────────────────┬─┘
            │                    │
            │ HTTP GET           │ opcional: MQTT
            ▼                    ▼
    ┌────────────────┐   ┌──────────────┐
    │  Celular       │   │ Nube (futuro)│
    │ • Navegador    │   │ • Base datos │
    │ • Dashboard    │   │ • Análisis   │
    └────────────────┘   └──────────────┘
```

## Componentes

### 1. Nodo MAIN

**Rol**: Punto central de recolección, almacenamiento y visualización.

**Hardware**:
- ESP32 DEVKIT con conexión WiFi
- Sensor de suelo RS485/Modbus
- Módulo GPS
- Tarjeta microSD (32GB recomendado)
- Batería opcional (puede estar conectado 24/7)

**Responsabilidades**:
- Conectarse a red WiFi local del celular
- Leer sensor propio
- Leer GPS propio
- Levantar servidor web HTTP
- Exponer API local para sensores
- Recibir mediciones de sensores remotos
- Guardar todas las mediciones en SD
- Generar recomendaciones agrícolas
- Servir dashboard visual
- Manejar descarga de CSV/JSON

**Almacenamiento**:
```
/sd/
├── config.json              # Configuración del nodo
├── nodes.json               # Registry de nodos conocidos
├── latest.json              # Última medición de cada nodo
├── measurements.csv         # Histórico de mediciones
├── recommendations.csv      # Histó de recomendaciones
└── logs/
    └── system.log           # Eventos del sistema
```

### 2. Nodos SENSOR

**Rol**: Puntos distribuidos de medición.

**Hardware** (idéntico al MAIN):
- ESP32 DEVKIT con conexión WiFi
- Sensor de suelo RS485/Modbus
- Módulo GPS
- Tarjeta microSD
- Batería (generalmente esta sí)

**Responsabilidades**:
- Conectarse a red WiFi del celular
- Leer sensor local
- Leer GPS local
- Guardar medición local en SD
- Descubrir ubicación del MAIN (mDNS)
- Enviar medición al MAIN por HTTP POST
- Reintentar envío si falla
- Guardar en cola pendiente si no hay conexión
- Entrar en deep sleep para ahorrar batería
- Despertar según intervalo configurado

**Almacenamiento**:
```
/sd/
├── config.json              # Configuración local
├── local_measurements.csv   # Mediciones del nodo
├── pending_queue.csv        # Mediciones sin enviar
└── logs/
    └── sensor.log           # Eventos del sensor
```

## Comunicación

### Protocolo SENSOR → MAIN

**Método**: HTTP POST sobre WiFi local

**Endpoint**: `POST http://zaque.local/api/measurements`

**Payload JSON**:
```json
{
  "api_key": "ZAQUE_LOCAL_KEY",
  "node_id": "zona_2",
  "node_name": "Lote de maiz",
  "role": "sensor",
  "timestamp": "2026-05-31T16:20:00",
  "lat": 4.7112,
  "lon": -74.0721,
  "soil_temperature": 22.8,
  "soil_humidity": 64.0,
  "electrical_conductivity": 820,
  "ph": 6.2,
  "nitrogen": 34,
  "phosphorus": 18,
  "potassium": 41,
  "battery_percent": 83,
  "firmware_version": "0.2.0"
}
```

**Respuesta MAIN**:
```json
{
  "status": "ok",
  "stored": true,
  "recommendation": "Humedad adecuada y pH dentro de rango aceptable.",
  "server_time": "2026-05-31T16:20:05"
}
```

### API HTTP del MAIN

| Método | Ruta | Descripción |
|---|---|---|
| GET | `/` | HTML dashboard |
| GET | `/dashboard` | Dashboard alternativo |
| GET | `/api/status` | Estado del sistema |
| GET | `/api/nodes` | Lista de nodos registrados |
| GET | `/api/measurements/latest` | Última medición de cada nodo |
| GET | `/api/history?node_id=zona_1` | Histórico de un nodo |
| POST | `/api/measurements` | Recibir medición de sensor |
| GET | `/download/measurements.csv` | Descargar CSV |

## Descubrimiento del MAIN

### Opción 1: mDNS (Preferida)
- El MAIN se anuncia como `zaque.local`
- Los sensores resuelven `http://zaque.local/api/measurements`
- Requiere soporte mDNS en red WiFi

### Opción 2: Fallback por IP
- Usar IP conocida: `192.168.43.50` (configurable)
- Solo funciona si el MAIN siempre recibe la misma IP

### Opción 3: UDP Discovery
- El MAIN responde broadcasts UDP en puerto específico
- Los sensores descubren MAIN automáticamente
- Implementación futura

## Flujos de Operación

### Inicio del Sistema

```
1. Campesino enciende zona móvil del celular
   └─ Crea red WiFi "NombreZonaMovil"

2. Enciende ESP32 MAIN
   └─ Conecta a WiFi
   └─ Inicia servidor web
   └─ Publica mDNS "zaque.local"
   └─ Espera mediciones

3. Enciende ESP32 SENSOR 1, SENSOR 2, ... SENSOR N
   └─ Cada uno conecta a WiFi
   └─ Cada uno busca "zaque.local"
   └─ Toman medición
   └─ Envían al MAIN
   └─ Guardan localmente
   └─ Entran en deep sleep
```

### Medición Periódica del SENSOR

```
Despertar por timer
  ↓
Conectar WiFi (retardo típico: 2-5s)
  ↓
Leer sensor local (retardo: variable)
  ↓
Leer GPS (retardo: 1-30s, depende de señal)
  ↓
Guardar en SD local
  ↓
Resolver zaque.local → IP
  ↓
POST a http://IP/api/measurements
  ├─ Si 200 OK: marcar como sincronizado
  └─ Si error: guardar en pending_queue.csv
  ↓
Deep sleep por N minutos (30 recomendado)
```

### Visualización en Dashboard

```
Campesino abre navegador en celular
  ↓
Entra a http://zaque.local
  ↓
Carga HTML dashboard (liviano, <100KB)
  ↓
JavaScript hace:
  └─ GET /api/measurements/latest
  └─ Renderiza tarjetas por nodo
  └─ Muestra coordenadas GPS
  └─ Muestra recomendaciones
  └─ Muestra batería
  ↓
Campesino consulta datos de su finca
```

## Almacenamiento de Datos

### Formato CSV Global (MAIN)

Archivo: `/measurements.csv`

```csv
timestamp,node_id,node_name,lat,lon,soil_temperature,soil_humidity,electrical_conductivity,ph,nitrogen,phosphorus,potassium,battery_percent,recommendation
2026-05-31T16:20:00,main,Nodo principal,4.7110,-74.0710,22.5,58,750,6.4,35,20,40,91,"Condiciones estables"
2026-05-31T16:20:05,zona_2,Lote de maiz,4.7112,-74.0721,22.8,64,820,6.2,34,18,41,83,"Humedad adecuada"
2026-05-31T16:20:10,zona_3,Cafetal,4.7120,-74.0730,21.2,52,600,5.8,28,16,32,71,"pH ligeramente ácido"
```

### Archivo latest.json (MAIN)

Actualizado después de cada medición. Permite que el dashboard cargue rápido.

```json
{
  "updated_at": "2026-05-31T16:20:10",
  "nodes": [
    {
      "node_id": "main",
      "node_name": "Nodo principal",
      "role": "main",
      "lat": 4.7110,
      "lon": -74.0710,
      "soil_humidity": 58,
      "ph": 6.4,
      "nitrogen": 35,
      "phosphorus": 20,
      "potassium": 40,
      "battery_percent": 91,
      "last_seen": "2026-05-31T16:20:00",
      "recommendation": "Condiciones estables."
    },
    {
      "node_id": "zona_2",
      "node_name": "Lote de maiz",
      "role": "sensor",
      "lat": 4.7112,
      "lon": -74.0721,
      "soil_humidity": 64,
      "ph": 6.2,
      "nitrogen": 34,
      "phosphorus": 18,
      "potassium": 41,
      "battery_percent": 83,
      "last_seen": "2026-05-31T16:20:05",
      "recommendation": "Humedad adecuada."
    }
  ]
}
```

## Recomendaciones Agrícolas

Motor de reglas simple basado en umbrales:

```
SI humedad < 30% → "Revisar riego"
SI humedad > 80% → "Verificar drenaje"
SI pH < 5.5     → "Suelo ácido, considerar enmienda"
SI pH > 7.5     → "Suelo alcalino, revisar tipo de fertilizante"
SI EC > 2000    → "Posible exceso de sales"
SI NPK < 30     → "Revisar fertilización"
SI batería < 20% → "Cargar nodo"
```

Las recomendaciones son orientativas y se muestran con disclaimer.

## Bajo Consumo (SENSOR)

Para maximizar autonomía de batería:

1. **WiFi**: Solo conectar cuando sea necesario (no mantener conexión)
2. **Lectura**: Tomar medición en ~5-10 segundos
3. **Transmisión**: Enviar datos en ~2-5 segundos
4. **Deep Sleep**: El 99% del tiempo en dormición

Con intervalo de 30 minutos:
- Tiempo activo: ~15 segundos
- Tiempo durmiendo: ~1799 segundos
- Consumo promedio: muy bajo

Puede funcionar de 1-3 meses con batería adecuada.

## Seguridad (MVP)

- API key simple en header (futuro: JWT)
- HTTPS no (futuro: cuando haya conectividad)
- Validación de JSON básica
- Sin autenticación (futuro)

## Escalabilidad

- Teórico: ESP32 puede servir múltiples clientes
- Práctico: Probar con 3-5 nodos
- Limitante: Hotspot del celular

Si necesita >10 nodos, usar router WiFi adicional.

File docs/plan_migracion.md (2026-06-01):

# Plan de Migración - Zaque Offline Multinodo

## Visión General

Migración de Zaque de una arquitectura basada en **ESP-NOW + MQTT + servidor remoto** a una arquitectura **WiFi local + HTTP + almacenamiento local**.

**Cambio principal**: De depender de internet y servidor remoto → Sistema autónomo local para zonas rurales.

---

## Fases de Implementación

### Fase 1: MAIN Autónomo (Alcance MVP)

**Objetivo**: Un nodo MAIN mide, almacena en SD y levanta dashboard web local.

**Duración estimada**: 1-2 semanas

**Tasks**:
- [ ] Implementar `sensor_reader.cpp` – Lectura RS485/Modbus
- [ ] Implementar `gps_reader.cpp` – Lectura GPS TinyGPS+
- [ ] Implementar `sd_logger.cpp` – Logging en microSD (CSV + JSON)
- [ ] Implementar `wifi_manager.cpp` – Conexión WiFi local
- [ ] Implementar `web_server.cpp` – Servidor HTTP básico
- [ ] Implementar `node_registry.cpp` – Registro interno de nodos
- [ ] Implementar `recommendations.cpp` – Motor de reglas simple
- [ ] Validar funcionamiento en hardware real
- [ ] Documentar procedimiento de carga

**Criterios de éxito**:
- [ ] MAIN se conecta a WiFi
- [ ] MAIN levanta servidor en puerto 80
- [ ] Dashboard accesible desde `http://zaque.local` (mDNS)
- [ ] MAIN toma medición de sensor local
- [ ] MAIN lee GPS local
- [ ] MAIN guarda medición en `/sd/measurements.csv`
- [ ] MAIN actualiza `/sd/latest.json`
- [ ] Dashboard muestra medición en tiempo real
- [ ] Recomendaciones agrícolas se muestran en dashboard

**Salida**:
- Firmware MAIN compilable y funcional
- Dashboard web local visible desde celular
- Datos almacenados en SD

---

### Fase 2: API Local del MAIN

**Objetivo**: MAIN expone endpoint HTTP para recibir mediciones de sensores.

**Duración estimada**: 1 semana

**Tasks**:
- [ ] Implementar `POST /api/measurements` en web_server.cpp
- [ ] Parsear JSON recibido con ArduinoJson
- [ ] Validar campos requeridos (node_id, humedad, pH, NPK, batería, etc.)
- [ ] Guardar medición en `/sd/measurements.csv`
- [ ] Actualizar `/sd/latest.json` con nueva medición
- [ ] Generar recomendación y incluir en respuesta
- [ ] Implementar validación de API key
- [ ] Implementar retry logic (timeout, errores HTTP)
- [ ] Documentar endpoints en `protocolo_api_local.md`
- [ ] Crear script de prueba (Python/Node/curl)

**Criterios de éxito**:
- [ ] Curl puede enviar JSON POST y recibe respuesta válida
- [ ] Medición se almacena en SD
- [ ] Dashboard MAIN actualiza cuando recibe POST
- [ ] API rechaza requests sin API key
- [ ] API rechaza JSON inválido con error 400
- [ ] Recomendación se retorna en respuesta

**Salida**:
- API local completamente funcional
- MAIN puede recibir y procesar mediciones remotas
- Documentación de endpoints

---

### Fase 3: Firmware SENSOR

**Objetivo**: Nodo SENSOR mide, guarda localmente en SD y envía al MAIN.

**Duración estimada**: 1-2 semanas

**Tasks**:
- [ ] Compilar config.h con `DEVICE_ROLE_SENSOR`
- [ ] Implementar `http_client.cpp` – Cliente HTTP
- [ ] Implementar mDNS lookup para encontrar `zaque.local`
- [ ] Implementar fallback a IP fija si mDNS falla
- [ ] Serializar medición a JSON
- [ ] Enviar POST a `/api/measurements`
- [ ] Manejar respuesta HTTP (éxito/error)
- [ ] Si falla: guardar en `/sd/pending_queue.csv`
- [ ] Implementar reintento automático (exponential backoff)
- [ ] Implementar deep sleep por `MEASUREMENT_INTERVAL_MINUTES`
- [ ] Optimizar para bajo consumo de batería
- [ ] Documentar procedimiento

**Criterios de éxito**:
- [ ] SENSOR conecta a WiFi
- [ ] SENSOR toma medición local
- [ ] SENSOR encuentra MAIN por mDNS
- [ ] SENSOR envía medición por HTTP POST
- [ ] MAIN recibe y almacena
- [ ] Dashboard MAIN muestra medición de SENSOR
- [ ] Si MAIN no está disponible, SENSOR guarda en pending_queue
- [ ] SENSOR entra en deep sleep
- [ ] Batería dura 1-3 meses

**Salida**:
- Firmware SENSOR compilable y funcional
- SENSOR envía datos al MAIN exitosamente
- Dato visible en dashboard MAIN
- Bajo consumo de batería validado

---

### Fase 4: Múltiples Sensores

**Objetivo**: Escalar a 3+ nodos conectados simultáneamente.

**Duración estimada**: 1 semana

**Tasks**:
- [ ] Compilar 3 instancias de SENSOR con diferentes NODE_ID
- [ ] Cargar en 3 ESP32 diferentes
- [ ] Conectar todos a mismo WiFi
- [ ] Verificar que todos se descubren mutuamente
- [ ] Verificar que MAIN recibe de todos simultáneamente
- [ ] Dashboard muestra todos los nodos
- [ ] Prueba de carga: 10+ mediciones simultáneas
- [ ] Validar integridad de datos en SD
- [ ] Documentar troubleshooting

**Criterios de éxito**:
- [ ] 3 sensores conectados al MAIN
- [ ] Cada sensor tiene su propia tarjeta SD
- [ ] Dashboard muestra datos de todos
- [ ] No hay conflictos de red
- [ ] MAIN no se satura

**Salida**:
- Sistema escalable a múltiples nodos
- Documentación de configuración multi-nodo

---

### Fase 5: Recomendaciones Agrícolas

**Objetivo**: Motor de reglas simple con recomendaciones por zona.

**Duración estimada**: 1 semana

**Tasks**:
- [ ] Expandir `recommendations.cpp` con más reglas
- [ ] Definir umbrales por cultivo/zona (configurable)
- [ ] Implementar niveles de alerta (OK / ATENCIÓN / CRÍTICO)
- [ ] Almacenar histórico de recomendaciones en `/sd/recommendations.csv`
- [ ] Dashboard muestra nivel de alerta por color
- [ ] Validar recomendaciones con agrónomo
- [ ] Documentar reglas en `/docs/recomendaciones.md`

**Criterios de éxito**:
- [ ] Reglas cubren: humedad, pH, NPK, batería, temperatura
- [ ] Recomendaciones son accionables
- [ ] Histórico se almacena correctamente
- [ ] Dashboard diferencia niveles de alerta visualmente

**Salida**:
- Motor de recomendaciones funcional
- Documentación de reglas

---

### Fase 6: Descubrimiento Automático

**Objetivo**: SENSOR encuentra MAIN sin IP fija.

**Duración estimada**: 1 semana

**Tasks**:
- [ ] Implementar mDNS en MAIN (ESPmDNS library)
- [ ] Implementar mDNS resolver en SENSOR
- [ ] Implementar fallback: UDP broadcast discovery
- [ ] Implementar fallback: IP configurada en config.h
- [ ] Validar en diferentes redes WiFi
- [ ] Documentar proceso de discovery

**Criterios de éxito**:
- [ ] SENSOR encuentra MAIN por mDNS en la mayoría de casos
- [ ] Fallback funciona si mDNS falla
- [ ] Documento de troubleshooting si discovery falla

**Salida**:
- Descubrimiento automático de MAIN
- Sistema más robusto

---

### Fase 7: Sincronización Opcional con Nube

**Objetivo**: MAIN puede sincronizar con servidor remoto cuando haya internet (futuro).

**Duración estimada**: 2-3 semanas

**Tasks**:
- [ ] Crear módulo `cloud_sync.cpp`
- [ ] Implementar cliente MQTT
- [ ] Implementar cliente REST API
- [ ] Detectar disponibilidad de internet (ping)
- [ ] Subir CSV/JSON cuando haya conexión
- [ ] Implementar sincronización en background
- [ ] Validar sin romper modo offline
- [ ] Documentación

**Criterios de éxito**:
- [ ] Sistema funciona igual sin internet (offline first)
- [ ] Cuando hay internet, sube datos automáticamente
- [ ] No hay conflictos de datos
- [ ] Dashboard remoto opcional en nube

**Salida**:
- Sistema completamente autónomo + opción de sincronización
- Backend Node.js preparado para recibir datos

---

## Timeline Propuesto

```
Semana 1:     Fase 1 (MAIN autónomo)
Semana 2:     Fase 2 (API local)
Semana 3:     Fase 3 (SENSOR)
Semana 4:     Fase 4 (Múltiples sensores)
Semana 5:     Fase 5 (Recomendaciones)
Semana 6:     Fase 6 (Descubrimiento automático)
Semanas 7-9:  Fase 7 (Sincronización con nube)
Semana 10:    Integración, testing, documentación
```

**Total estimado**: 10-12 semanas para MVP + cloud.

---

## Dependencias Entre Fases

```
Fase 1 (MAIN autónomo)
    ↓
Fase 2 (API local del MAIN)
    ↓
Fase 3 (Firmware SENSOR)
    ↓
Fase 4 (Múltiples sensores)
    ↓
Fase 5 (Recomendaciones)

Fase 6 (Descubrimiento) [paralelo a Fase 4-5]
Fase 7 (Nube) [paralelo a otras, independiente]
```

---

## Criterios de Éxito Global

Al final de todas las fases:

- [ ] 1 nodo MAIN + 3+ nodos SENSOR funcionando
- [ ] Dashboard accesible desde celular en red local
- [ ] Todos los datos almacenados en microSD
- [ ] Sistema funciona 100% sin internet
- [ ] Baterías duran 1-3 meses
- [ ] Documentación completa
- [ ] Código en GitHub público
- [ ] Compilable en Arduino IDE estándar
- [ ] No requiere dependencias externas complicadas
- [ ] Testeado en campo con agricultores

---

## Riesgos Mitigados

| Riesgo | Impacto | Mitigación |
|---|---|---|
| Conflicto GPIO 13 | Alto | Usar GPIO13 MUX (GPS en init, SD en medición) |
| Consumo WiFi alto | Alto | Deep sleep agresivo en SENSOR |
| SD corrupción | Medio | Escribir cerrar correctamente |
| Dashboard pesado | Medio | HTML/CSS/JS <100KB |
| GPS sin señal | Medio | Usar última ubicación válida |
| Pérdida conexión MAIN | Medio | Guardar pending_queue en SD |
| Límite de dispositivos | Medio | Máximo 10-15 nodos por hotspot |
| Memoria ESP32 limitada | Bajo | JSON pequeños, código eficiente |

---

## Notas Importantes

1. **Prioridad MAIN**: Asegurar que MAIN funciona primero (base de todo)
2. **Testing en campo**: Validar con agricultores desde Fase 1
3. **Documentación**: Escribir en paralelo a implementación
4. **Open Source**: Todo público en GitHub
5. **Bajo costo**: Hardware accesible (<$50 USD por nodo)
6. **Sostenibilidad**: Que otros puedan mantener y extender

---

## Librerías Requeridas

```
Arduino IDE → Manage Libraries:

- ModbusMaster (RS485 Modbus)
- TinyGPSPlus (GPS NEO-6M)
- SD (tarjeta microSD)
- SPI (comunicación SPI)
- WiFi (WiFi ESP32)
- WebServer (servidor HTTP)
- HTTPClient (cliente HTTP)
- ArduinoJson (procesamiento JSON)
- ESPmDNS (mDNS multicast)
```

---

## Próximos Pasos Inmediatos

1. ✅ Crear estructura de carpetas
2. ✅ Crear headers base
3. ✅ Crear config.h unificado
4. ✅ Crear firmware skeleton (zaque_device.ino)
5. ✅ Crear dashboard HTML embebido
6. ⏭️ **Fase 1 - Implementar sensor_reader.cpp**
7. ⏭️ **Fase 1 - Implementar gps_reader.cpp**
8. ⏭️ **Fase 1 - Implementar sd_logger.cpp**
9. ...

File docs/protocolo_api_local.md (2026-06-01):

# Protocolo API Local - Zaque Offline

## Overview

El API local es una interfaz HTTP simple que permite a los nodos SENSOR enviar mediciones y obtener recomendaciones del nodo MAIN.

El objetivo es ser simple, liviano y sin dependencias externas de autenticación complicada.

## Endpoints del MAIN

### GET /
Retorna el dashboard HTML.

**Respuesta**:
- Content-Type: `text/html`
- Body: HTML del dashboard (embebido en el firmware)

**Ejemplo**:
```bash
curl http://zaque.local/
```

### GET /dashboard
Alternativa para obtener el dashboard (misma respuesta que GET /).

### GET /api/status
Estado general del sistema MAIN.

**Respuesta**:
```json
{
  "status": "ok",
  "role": "main",
  "node_id": "main",
  "firmware": "0.2.0",
  "uptime_seconds": 3600,
  "connected_sensors": 2,
  "sd_available_mb": 29000,
  "wifi_signal_strength": -67
}
```

**Ejemplo**:
```bash
curl http://zaque.local/api/status
```

### GET /api/nodes
Lista de todos los nodos conocidos (MAIN + SENSOR registrados).

**Respuesta**:
```json
{
  "nodes": [
    {
      "node_id": "main",
      "node_name": "Nodo principal",
      "role": "main",
      "last_measurement": "2026-05-31T16:20:00",
      "battery_percent": 91,
      "is_active": true
    },
    {
      "node_id": "zona_2",
      "node_name": "Lote de maiz",
      "role": "sensor",
      "last_measurement": "2026-05-31T16:19:55",
      "battery_percent": 83,
      "is_active": true
    }
  ]
}
```

**Ejemplo**:
```bash
curl http://zaque.local/api/nodes
```

### GET /api/measurements/latest
Última medición registrada de cada nodo.

**Respuesta**: (Archivo `/sd/latest.json` del MAIN)
```json
{
  "updated_at": "2026-05-31T16:20:10",
  "nodes": [
    {
      "node_id": "main",
      "node_name": "Nodo principal",
      "role": "main",
      "lat": 4.7110,
      "lon": -74.0710,
      "soil_humidity": 58,
      "ph": 6.4,
      "nitrogen": 35,
      "phosphorus": 20,
      "potassium": 40,
      "battery_percent": 91,
      "last_seen": "2026-05-31T16:20:00",
      "recommendation": "Condiciones estables."
    },
    {
      "node_id": "zona_2",
      "node_name": "Lote de maiz",
      "role": "sensor",
      "lat": 4.7112,
      "lon": -74.0721,
      "soil_humidity": 64,
      "ph": 6.2,
      "nitrogen": 34,
      "phosphorus": 18,
      "potassium": 41,
      "battery_percent": 83,
      "last_seen": "2026-05-31T16:20:05",
      "recommendation": "Humedad adecuada."
    }
  ]
}
```

**Ejemplo**:
```bash
curl http://zaque.local/api/measurements/latest
```

### GET /api/history?node_id=zona_2
Histórico de mediciones de un nodo específico (últimas N registros).

**Parámetros**:
- `node_id`: ID del nodo (requerido)
- `limit`: Número de registros (opcional, default: 100)

**Respuesta**:
```json
{
  "node_id": "zona_2",
  "measurements": [
    {
      "timestamp": "2026-05-31T16:20:05",
      "lat": 4.7112,
      "lon": -74.0721,
      "soil_temperature": 22.8,
      "soil_humidity": 64.0,
      "electrical_conductivity": 820,
      "ph": 6.2,
      "nitrogen": 34,
      "phosphorus": 18,
      "potassium": 41,
      "battery_percent": 83
    },
    {
      "timestamp": "2026-05-31T15:50:10",
      "lat": 4.7112,
      "lon": -74.0721,
      "soil_temperature": 22.5,
      "soil_humidity": 62.0,
      "electrical_conductivity": 810,
      "ph": 6.3,
      "nitrogen": 35,
      "phosphorus": 19,
      "potassium": 40,
      "battery_percent": 85
    }
  ]
}
```

**Ejemplo**:
```bash
curl "http://zaque.local/api/history?node_id=zona_2&limit=50"
```

### POST /api/measurements
Recibir medición de un nodo SENSOR.

**Headers**:
- `Content-Type: application/json`

**Body Request** (enviado por SENSOR):
```json
{
  "api_key": "ZAQUE_LOCAL_KEY",
  "node_id": "zona_2",
  "node_name": "Lote de maiz",
  "role": "sensor",
  "timestamp": "2026-05-31T16:20:00",
  "lat": 4.7112,
  "lon": -74.0721,
  "soil_temperature": 22.8,
  "soil_humidity": 64.0,
  "electrical_conductivity": 820,
  "ph": 6.2,
  "nitrogen": 34,
  "phosphorus": 18,
  "potassium": 41,
  "battery_percent": 83,
  "firmware_version": "0.2.0"
}
```

**Body Response** (del MAIN):
```json
{
  "status": "ok",
  "stored": true,
  "recommendation": "Humedad adecuada y pH dentro de rango aceptable.",
  "server_time": "2026-05-31T16:20:05"
}
```

**Códigos de respuesta**:
- `200 OK`: Medición recibida y almacenada
- `400 Bad Request`: JSON inválido o campos faltantes
- `401 Unauthorized`: api_key incorrecta
- `500 Internal Server Error`: Error al guardar

**Ejemplo con curl**:
```bash
curl -X POST http://zaque.local/api/measurements \
  -H "Content-Type: application/json" \
  -d '{
    "api_key": "ZAQUE_LOCAL_KEY",
    "node_id": "zona_2",
    "node_name": "Lote de maiz",
    "role": "sensor",
    "timestamp": "2026-05-31T16:20:00",
    "lat": 4.7112,
    "lon": -74.0721,
    "soil_temperature": 22.8,
    "soil_humidity": 64.0,
    "electrical_conductivity": 820,
    "ph": 6.2,
    "nitrogen": 34,
    "phosphorus": 18,
    "potassium": 41,
    "battery_percent": 83,
    "firmware_version": "0.2.0"
  }'
```

### GET /download/measurements.csv
Descargar archivo CSV con todas las mediciones guardadas.

**Respuesta**:
- Content-Type: `text/csv`
- Body: Archivo CSV en formato:
  ```csv
  timestamp,node_id,node_name,lat,lon,soil_temperature,soil_humidity,electrical_conductivity,ph,nitrogen,phosphorus,potassium,battery_percent,recommendation
  2026-05-31T16:20:00,zona_2,Lote de maiz,4.7112,-74.0721,22.8,64,820,6.2,34,18,41,83,"Humedad adecuada"
  ```

**Ejemplo**:
```bash
curl http://zaque.local/download/measurements.csv > measurements.csv
```

## Validación y Errores

### Validación de entrada (POST /api/measurements)

Campos requeridos:
- `api_key` (string)
- `node_id` (string, max 32 chars)
- `node_name` (string, max 64 chars)
- `role` (string: "sensor" or "main")
- `timestamp` (string ISO 8601)
- `lat` (float, -90 a 90)
- `lon` (float, -180 a 180)
- `soil_humidity` (float, 0-100)
- `ph` (float, 0-14)
- `nitrogen` (int, 0-300)
- `phosphorus` (int, 0-300)
- `potassium` (int, 0-300)
- `battery_percent` (int, 0-100)

Campos opcionales:
- `soil_temperature` (float)
- `electrical_conductivity` (int)
- `firmware_version` (string)

### Códigos de error

```json
{
  "status": "error",
  "code": "INVALID_JSON",
  "message": "JSON malformed or incomplete"
}
```

Posibles códigos de error:
- `INVALID_JSON`: JSON inválido o incompleto
- `MISSING_FIELD`: Campo requerido ausente
- `INVALID_API_KEY`: api_key incorrecta
- `INVALID_VALUE`: Valor fuera de rango
- `STORAGE_ERROR`: Error al guardar en SD
- `INTERNAL_ERROR`: Error interno del servidor

## Seguridad

### API Key

Por defecto, se requiere api_key en POST /api/measurements.

Valor por defecto: `ZAQUE_LOCAL_KEY`

Se recomienda:
1. Cambiar en `config.h` antes de compilar
2. Futuro: Implementar JWT
3. Futuro: Implementar certificados TLS (cuando haya internet)

### HTTPS

No está implementado en MVP (se usa HTTP sobre red local).

Futuro: Agregar soporte HTTPS cuando haya conectividad a internet.

### Validación

- Se validan todos los valores numéricos
- Se validan coordenadas GPS
- Se valida timestamp ISO 8601
- Se truncan strings a longitud máxima

## Rate Limiting

No hay rate limiting en MVP. Futuro: Implementar si es necesario.

## Versionado

Versión de API: 1.0

Se puede consultar en GET /api/status.

Cambios futuros que requieren versionado:
- Agregar nuevos campos obligatorios
- Cambiar estructura de respuesta
- Cambiar códigos de error

## Ejemplos de Integración

### Python

```python
import requests
import json
from datetime import datetime

def send_measurement(main_ip, measurement):
    url = f"http://{main_ip}/api/measurements"
    headers = {"Content-Type": "application/json"}
    
    measurement['timestamp'] = datetime.now().isoformat()
    measurement['api_key'] = 'ZAQUE_LOCAL_KEY'
    
    response = requests.post(url, json=measurement, headers=headers)
    return response.json()

# Ejemplo
meas = {
    "node_id": "zona_2",
    "node_name": "Lote de maiz",
    "role": "sensor",
    "lat": 4.7112,
    "lon": -74.0721,
    "soil_humidity": 64.0,
    "ph": 6.2,
    "nitrogen": 34,
    "phosphorus": 18,
    "potassium": 41,
    "battery_percent": 83
}

result = send_measurement("192.168.43.50", meas)
print(result)
```

### JavaScript

```javascript
async function sendMeasurement(mainIP, measurement) {
    const url = `http://${mainIP}/api/measurements`;
    
    measurement.timestamp = new Date().toISOString();
    measurement.api_key = 'ZAQUE_LOCAL_KEY';
    
    const response = await fetch(url, {
        method: 'POST',
        headers: {'Content-Type': 'application/json'},
        body: JSON.stringify(measurement)
    });
    
    return await response.json();
}

// Ejemplo
const meas = {
    node_id: "zona_2",
    node_name: "Lote de maiz",
    role: "sensor",
    lat: 4.7112,
    lon: -74.0721,
    soil_humidity: 64.0,
    ph: 6.2,
    nitrogen: 34,
    phosphorus: 18,
    potassium: 41,
    battery_percent: 83
};

sendMeasurement("192.168.43.50", meas).then(console.log);
```

## Testing

Para probar el API sin ESP32:

```bash
# Obtener estado
curl http://zaque.local/api/status

# Enviar medición fake
curl -X POST http://zaque.local/api/measurements \
  -H "Content-Type: application/json" \
  -d @measurement.json

# Ver última medición
curl http://zaque.local/api/measurements/latest

# Descargar CSV
curl http://zaque.local/download/measurements.csv > data.csv
```

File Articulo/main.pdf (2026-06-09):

# ZAQUE: Sistema Distribuido de Monitoreo Agr´ıcola Local para Zonas Rurales sin Conectividad a Internet

Alejandro Roa Aparicio, Laura Sof´ıa Holgu´ın Giraldo, Andres Felipe Guarnizo Saavedra ´ Universidad EAN, Colombia

Resumen—La agricultura de precision ha revolucionado la ´
produccion agr ´ | ´ıcola mediante la incorporacion de tecnolog ´ | ´ıas
IoT. Sin embargo, gran parte de las soluciones disponibles dependen de conectividad permanente a Internet y servicios en la nube, limitando su implementacion en zonas rurales donde ´ la infraestructura de telecomunicaciones es insuficiente. Este art´ıculo presenta ZAQUE, un sistema distribuido de monitoreo
agr´ıcola local disenado espec ˜ | ´ıficamente para operar en entornos
con conectividad limitada. La arquitectura propuesta integra una red de nodos ESP32, uno configurado como estacion principal ´ (MAIN) y multiples nodos sensores (SENSOR), comunicados ´ mediante WiFi local. Cada nodo incorpora sensores Modbus
RS485 para medicion multiparam ´ | etrica del suelo, m ´ | odulos GPS ´
para georreferenciacion, y almacenamiento local en microSD ´ para garantizar persistencia de datos. El nodo MAIN expone un dashboard web embebido accesible desde dispositivos moviles ´ sin requerir acceso a Internet. El sistema incluye un motor de recomendaciones agr´ıcolas basado en reglas que genera alertas utiles en lenguaje natural para el campesino. Los resultados de- ´ muestran la viabilidad de una solucion de bajo costo aproximado ´ de USD 100 por nodo capaz de apoyar agricultura de precision´ en comunidades rurales con conectividad limitada.
I. INTRODUCCION´
La agricultura moderna enfrenta desaf´ıos crecientes: aumento de poblacion global, limitaciones de agua dulce, degrada- ´
cion de suelos y presi ´ | on por mejorar rendimientos. En este ´
contexto, la agricultura de precision emerge como estrategia ´ tecnologica fundamental que permite monitorear variables am- ´ bientales a nivel microlocal para optimizar recursos naturales. El Internet de las Cosas (IoT) ha democratizado el acceso a sensores de bajo costo capaces de recopilar datos ambientales. Sin embargo, la mayor´ıa de soluciones IoT comerciales dependen de plataformas en la nube, requiriendo conectividad permanente a Internet. En Colombia, la conectividad rural
continua siendo una barrera para la adopci ´ | on de tecnolog ´ | ´ıas
digitales en el campo.
ZAQUE surge como respuesta a esta brecha: un sistema de monitoreo agr´ıcola que funciona completamente offline en redes WiFi locales, permitiendo que un campesino use
la zona movil de su celular para conectar m ´ | ultiples sensores ´
distribuidos en su finca y visualizar toda la informacion desde ´ un navegador web en su dispositivo movil. ´

II. ARQUITECTURA DEL SISTEMA
II-A. Vision General ´
ZAQUE implementa una arquitectura distribuida multinodo con dos roles diferenciados ejecutados en hardware identico, ´

basado en ESP32:

Nodo MAIN: Estacion central que act ´ | ua como servidor ´
web, procesador de datos y almacenamiento principal. Ejecuta permanentemente un servidor HTTP local accesible desde el navegador.
Nodos SENSOR: Dispositivos distribuidos en el terreno agr´ıcola que ejecutan ciclos de medicion peri ´ odica, ´ env´ıan datos al MAIN mediante HTTP POST, y entran en deep sleep para conservar energ´ıa.
La comunicacion entre nodos ocurre a trav ´ | es de una red Wi- ´
Fi local, t´ıpicamente la zona movil del celular del campesino, ´ eliminando la dependencia de infraestructura externa.

II-B. Componentes Principales

II-B1. Nodo MAIN: El nodo MAIN implementa las siguientes responsabilidades:

1. Adquisicion de datos ´ | : Lectura local de sensores Mod-
bus RS485, GPS y bater´ıa.
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

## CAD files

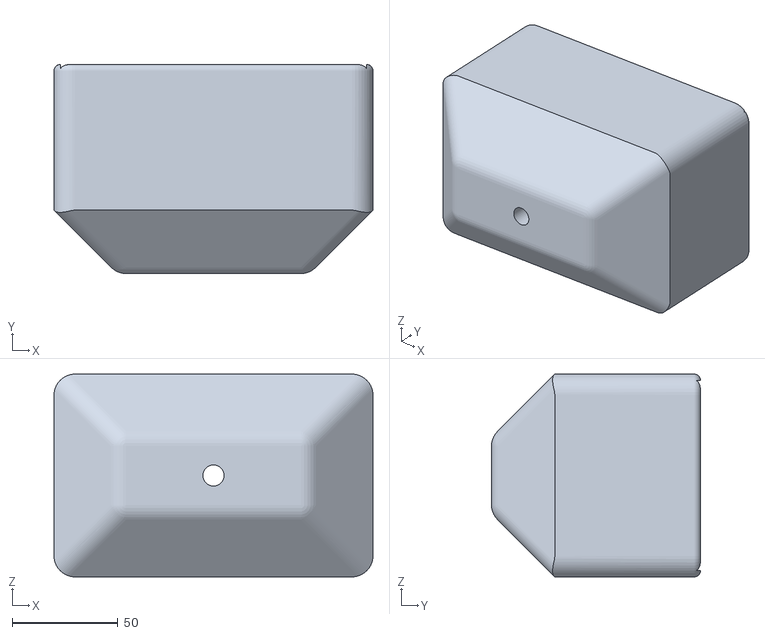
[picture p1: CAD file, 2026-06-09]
caja2.STL
151.0 x 99.0 x 96.0

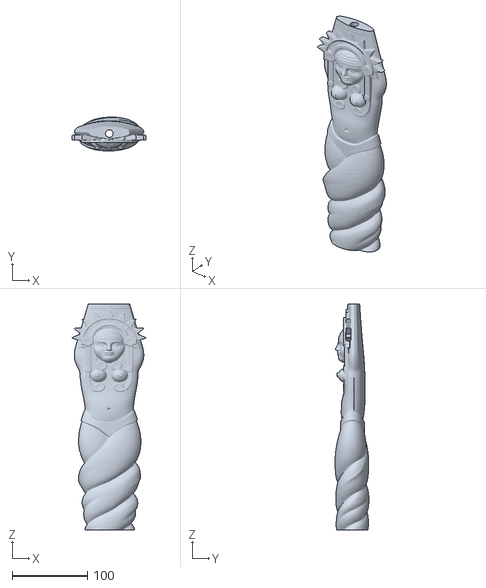
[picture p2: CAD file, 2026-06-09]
case.stl
98.1 x 45.0 x 300.0

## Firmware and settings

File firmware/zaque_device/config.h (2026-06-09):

#pragma once

// ============================================================================
// CONFIGURACIÓN DE ROLES
// ============================================================================
#define DEVICE_ROLE_MAIN 1
#define DEVICE_ROLE_SENSOR 2

// Cambiar a DEVICE_ROLE_SENSOR para compilar firmware de sensor
#define DEVICE_ROLE DEVICE_ROLE_MAIN

// ============================================================================
// IDENTIFICACIÓN DEL NODO
// ============================================================================
#if DEVICE_ROLE == DEVICE_ROLE_MAIN
  #define NODE_ID "zaque"
  #define NODE_NAME "Nodo principal - Casa finca"
#else
  #define NODE_ID "zona_2"
  #define NODE_NAME "Lote de maiz"
#endif

#define FIRMWARE_VERSION "0.2.0"

// ============================================================================
// CONFIGURACIÓN WiFi
// ============================================================================
// NOTA: Para producción, mover a secrets.h
#define WIFI_SSID "Zaque"
#define WIFI_PASSWORD "free12345"
#define WIFI_TIMEOUT_MS 10000

// ============================================================================
// CONFIGURACIÓN DEL NODO MAIN
// ============================================================================
#define MAIN_HOST "zaque.local"
#define MAIN_IP_FALLBACK "192.168.43.50"
#define MAIN_PORT 80

// ============================================================================
// CONFIGURACIÓN DEL NODO SENSOR
// ============================================================================
#define MEASUREMENT_INTERVAL_MINUTES 30
#define SENSOR_SEND_TIMEOUT_MS 5000
#define SENSOR_SEND_MAX_RETRIES 3

// ============================================================================
// PINES - CONSERVADOS DEL PROYECTO ANTERIOR
// ============================================================================
#define GPIO_0_DIVISOR_TENSION 0    // Divisor de tensión para batería (ADC)
#define POWER_PIN 2                 // Control de potencia
#define POWER_PIN2 4                // Control de potencia 2

// ============================================================================
// PINES - SONDA MULTIPARAMÉTRICA RS485/Modbus
// ============================================================================
#define RXD2 16                     // RX del RS485
#define TXD2 17                     // TX del RS485
#define ANALOG_IN_SENSOR A6         // Entrada analógica del sensor

// ============================================================================
// PINES - GPS
// ============================================================================
#define GPIO_TX_GPS 12              // TX del GPS
#define GPIO_RX_GPS 13              // RX del GPS

// Ubicación por defecto (si el GPS falla)
#define DEFAULT_LATITUDE 4.663198720911477f
#define DEFAULT_LONGITUDE -74.05499259771824f

// ============================================================================
// PINES - TARJETA microSD (SPI)
// ============================================================================
#define GPIO_SD_CS 5                // Chip Select
#define GPIO_SD_SCK 23              // Clock (SPI)
#define GPIO_SD_MOSI 18             // MOSI
#define GPIO_SD_MISO 19             // MISO

// ============================================================================
// CONFIGURACIÓN DE MEDICIÓN
// ============================================================================
#define MEASUREMENT_BUFFER_SIZE 256

// Modbus configuration
#define MODBUS_SLAVE_ADDRESS 1
#define MODBUS_BAUD_RATE 4800

// ============================================================================
// CONFIGURACIÓN DE ALMACENAMIENTO (microSD)
// ============================================================================
#define SD_LOG_DIR "/logs"
#define SD_MEASUREMENTS_FILE "/measurements.csv"
#define SD_LATEST_FILE "/latest.json"
#define SD_CONFIG_FILE "/config.json"
#define SD_NODES_FILE "/nodes.json"

// ============================================================================
// CONFIGURACIÓN DE API
// ============================================================================
#define API_KEY "ZAQUE_LOCAL_KEY"   // NOTA: Mover a secrets.h

// ============================================================================
// SEGURIDAD
// ============================================================================
#define USE_API_KEY true
#define ENABLE_DEBUG_SERIAL true

#if ENABLE_DEBUG_SERIAL
  #define DEBUG_BAUD_RATE 115200
#endif

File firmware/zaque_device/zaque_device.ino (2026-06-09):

/*
 * ZAQUE - Monitoreo Agrícola Local Distribuido
 * 
 * Firmware unificado para nodos MAIN y SENSOR
 * 
 * Arquitectura: Red WiFi local del celular → MAIN (web + API) ← SENSOR (mediciones)
 * Almacenamiento: Todos los datos en microSD local
 * 
 * Este firmware es compilado con DEVICE_ROLE definido en config.h
 * DEVICE_ROLE_MAIN:   Nodo principal con dashboard web
 * DEVICE_ROLE_SENSOR: Nodo sensor que envía datos al MAIN
 * 
 * Versión: 0.2.0
 */

#include "config.h"
#include "types.h"
#include "sensor_reader.h"
#include "gps_reader.h"
#include "sd_logger.h"
#include "wifi_manager.h"
#include "recommendations.h"

// Roles específicos
#if DEVICE_ROLE == DEVICE_ROLE_MAIN
  #include "web_server.h"
  #include "node_registry.h"
#endif

#if DEVICE_ROLE == DEVICE_ROLE_SENSOR
  #include "http_client.h"
#endif

// ============================================================================
// VARIABLES GLOBALES
// ============================================================================

SensorReader* sensor_reader = nullptr;
GPSReader* gps_reader = nullptr;
SDLogger* sd_logger = nullptr;
WiFiManager* wifi_manager = nullptr;
Recommendations* recommendations = nullptr;

#if DEVICE_ROLE == DEVICE_ROLE_MAIN
  Web_ServerInterface* web_server = nullptr;
  NodeRegistry* node_registry = nullptr;
#endif

#if DEVICE_ROLE == DEVICE_ROLE_SENSOR
  HTTP_ClientInterface* http_client = nullptr;
#endif

unsigned long last_measurement_time = 0;
unsigned long awake_start_time = 0;
bool is_in_initial_awake = true;

// ============================================================================
// SETUP - Inicialización
// ============================================================================

void setup() {
  awake_start_time = millis();
  // Serial para debug
#if ENABLE_DEBUG_SERIAL
  Serial.begin(DEBUG_BAUD_RATE);
  delay(1000);
  
  Serial.println("\n\n=== ZAQUE Initialization ===");
  Serial.printf("Device Role: %s\n", 
    DEVICE_ROLE == DEVICE_ROLE_MAIN ? "MAIN" : "SENSOR");
  Serial.printf("Node ID: %s\n", NODE_ID);
  Serial.printf("Firmware: %s\n", FIRMWARE_VERSION);
#endif

  // Inicializar sensor de suelo
#if ENABLE_DEBUG_SERIAL
  Serial.println("→ Initializing soil sensor...");
#endif
  sensor_reader = createSensorReader();
  sensor_reader->init();

  // Inicializar GPS
#if ENABLE_DEBUG_SERIAL
  Serial.println("→ Initializing GPS...");
#endif
  gps_reader = createGPSReader();
  gps_reader->init();

  // Inicializar microSD
#if ENABLE_DEBUG_SERIAL
  Serial.println("→ Initializing SD card...");
#endif
  sd_logger = createSDLogger();
  sd_logger->init();

  // Conectar a WiFi
#if ENABLE_DEBUG_SERIAL
  Serial.println("→ Connecting to WiFi...");
#endif
  wifi_manager = createWiFiManager();
  wifi_manager->init(WIFI_SSID, WIFI_PASSWORD);

  // Inicializar recomendaciones
  recommendations = createRecommendationEngine();

  // Inicialización específica por rol
#if DEVICE_ROLE == DEVICE_ROLE_MAIN
  Serial.println("→ Starting web server...");
  web_server = createWebServer();
  web_server->init(MAIN_PORT);

  node_registry = createNodeRegistry();
  node_registry->init();
  
#endif

#if DEVICE_ROLE == DEVICE_ROLE_SENSOR
  Serial.println("→ Initializing HTTP client...");
  http_client = createHTTPClient();
  http_client->init(MAIN_HOST, MAIN_PORT);
#endif

#if ENABLE_DEBUG_SERIAL
  Serial.println("✓ Initialization complete");
#endif
}

// ============================================================================
// LOOP PRINCIPAL
// ============================================================================

void loop() {
  unsigned long current_time = millis();

#if DEVICE_ROLE == DEVICE_ROLE_MAIN
  // Gestión del periodo inicial de 5 minutos para el MAIN
  if (is_in_initial_awake) {
    if (current_time - awake_start_time > (5 * 60 * 1000)) {
      is_in_initial_awake = false;
#if ENABLE_DEBUG_SERIAL
      Serial.println("→ Initial 5-minute awake period finished. Going to deep sleep...");
      Serial.flush();
#endif
      // Cleanup antes de dormir
      if (sensor_reader) sensor_reader->shutdown();
      if (gps_reader) gps_reader->shutdown();
      if (sd_logger) sd_logger->shutdown();
      if (wifi_manager) wifi_manager->shutdown();
      if (web_server) web_server->shutdown();

      esp_sleep_enable_timer_wakeup(MEASUREMENT_INTERVAL_MINUTES * 60 * 1000000);
      esp_deep_sleep_start();
    }
  }
#endif

  // Determinar el intervalo de medición
  unsigned long interval = (MEASUREMENT_INTERVAL_MINUTES * 60 * 1000);
#if DEVICE_ROLE == DEVICE_ROLE_MAIN
  if (is_in_initial_awake) {
    interval = 30 * 1000; // Medir cada 30 segundos durante los primeros 5 minutos
  }
#endif

  // Verificar si es hora de tomar una nueva medición
  if (current_time - last_measurement_time < interval) {
    // Aún no es hora; hacer tareas del rol actual

#if DEVICE_ROLE == DEVICE_ROLE_MAIN
    // El MAIN está siempre atendiendo el servidor web
    web_server->handleRequests();
    delay(100); // Pequeño delay para no consumir CPU
#else
    // El SENSOR puede hacer otras tareas o dormir parcialmente
    delay(1000);
#endif
    return;
  }

  // Es hora de tomar medición
  last_measurement_time = current_time;

#if ENABLE_DEBUG_SERIAL
  Serial.println("\n→ Taking measurement...");
#endif

  Measurement m;
  
  // Llenar metadatos
  strncpy(m.node_id, NODE_ID, sizeof(m.node_id) - 1);
  strncpy(m.node_name, NODE_NAME, sizeof(m.node_name) - 1);
  strncpy(m.role, DEVICE_ROLE == DEVICE_ROLE_MAIN ? "main" : "sensor", sizeof(m.role) - 1);
  strncpy(m.firmware_version, FIRMWARE_VERSION, sizeof(m.firmware_version) - 1);
  m.timestamp_ms = millis();

  // Leer sensor
  if (!sensor_reader->read(m)) {
#if ENABLE_DEBUG_SERIAL
    Serial.println("✗ Failed to read sensor");
#endif
    return;
  }

  // Leer GPS (siempre obtiene ubicación, por defecto o válida)
  if (gps_reader->read(m.latitude, m.longitude)) {
    m.gps_valid = true;
#if ENABLE_DEBUG_SERIAL
    Serial.printf("✓ Location obtained: %.6f, %.6f\n", m.latitude, m.longitude);
#endif
  } else {
    // Esto no debería ocurrir con la nueva lógica que siempre usa ubicación por defecto
    m.gps_valid = false;
#if ENABLE_DEBUG_SERIAL
    Serial.println("! GPS reader failed");
#endif
  }

  // Generar recomendación
  recommendations->generateRecommendation(m, m.recommendation, sizeof(m.recommendation));

  // Guardar en SD local
#if ENABLE_DEBUG_SERIAL
  Serial.println("→ Saving to SD...");
#endif
  if (!sd_logger->logMeasurement(m)) {
#if ENABLE_DEBUG_SERIAL
    Serial.println("✗ Failed to save to SD");
#endif
  }

  // Acciones específicas por rol
#if DEVICE_ROLE == DEVICE_ROLE_MAIN
  // El MAIN guarda su propia medición en el registro de nodos
  node_registry->updateLocalNode(m);
  
#if ENABLE_DEBUG_SERIAL
  Serial.println("✓ Main measurement recorded");
#endif

#endif

#if DEVICE_ROLE == DEVICE_ROLE_SENSOR
  // El SENSOR envía la medición al MAIN
#if ENABLE_DEBUG_SERIAL
  Serial.println("→ Sending measurement to MAIN...");
#endif
  
  if (!http_client->sendWithRetry(m, SENSOR_SEND_MAX_RETRIES)) {
#if ENABLE_DEBUG_SERIAL
    Serial.println("! Failed to send to MAIN, saved for retry");
#endif
  }

  // Entrar en deep sleep
#if ENABLE_DEBUG_SERIAL
  Serial.printf("→ Going to deep sleep for %d minutes...\n", 
    MEASUREMENT_INTERVAL_MINUTES);
  Serial.flush();
#endif
  
  // Cleanup antes de dormir
  if (sensor_reader) sensor_reader->shutdown();
  if (gps_reader) gps_reader->shutdown();
  if (sd_logger) sd_logger->shutdown();
  if (wifi_manager) wifi_manager->shutdown();
  if (http_client) http_client->shutdown();

  esp_sleep_enable_timer_wakeup(MEASUREMENT_INTERVAL_MINUTES * 60 * 1000000);
  esp_deep_sleep_start();
  
#endif
}

// ============================================================================
// NOTA: Implementar en archivos separados:
// - sensor_reader.cpp
// - gps_reader.cpp
// - sd_logger.cpp
// - wifi_manager.cpp
// - http_client.cpp (solo SENSOR)
// - web_server.cpp (solo MAIN)
// - node_registry.cpp (solo MAIN)
// - recommendations.cpp
// ============================================================================

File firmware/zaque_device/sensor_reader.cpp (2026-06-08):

#include "sensor_reader.h"
#include "config.h"
#include <HardwareSerial.h>
#include <ModbusMaster.h>

// Instancia del objeto Modbus
ModbusMaster node;
static HardwareSerial modbus_serial(2);  // UART2 para RS485

class ModbusSensorReaderImpl : public SensorReaderImpl {
public:
  void init() override {
    // Configurar pines de alimentación
    pinMode(POWER_PIN, OUTPUT);
    pinMode(POWER_PIN2, OUTPUT);
    
    // Enceder alimentación del sensor/módulo
    digitalWrite(POWER_PIN, HIGH);
    digitalWrite(POWER_PIN2, HIGH);
    
    // Esperar a que el sensor se estabilice (como en Prueba_Sensor.ino)
    delay(5000);

    // Inicializar UART2 para comunicación Modbus
    modbus_serial.begin(MODBUS_BAUD_RATE, SERIAL_8N1, RXD2, TXD2);
    
    // Configurar cliente Modbus
    node.begin(MODBUS_SLAVE_ADDRESS, modbus_serial);
    
#if ENABLE_DEBUG_SERIAL
    Serial.println("✓ Modbus sensor initialized and powered");
#endif
  }

  bool read(Measurement& m) override {
    // Leer registros Modbus del sensor NPK
    return readModbusRegisters(m);
  }

  void shutdown() override {
    digitalWrite(POWER_PIN, LOW);
    digitalWrite(POWER_PIN2, LOW);
    modbus_serial.end();
  }

private:
  bool readModbusRegisters(Measurement& m) {
    // Variables Modbus
    uint8_t result;

    // Intentar lectura (reintento 3 veces si falla)
    for (int attempt = 0; attempt < 3; attempt++) {
      // Leer 7 registros Modbus desde la dirección 0x0000 (Holding Registers como en Prueba_Sensor.ino)
      // Registro 0: Humedad
      // Registro 1: Temperatura
      // Registro 2: Conductividad
      // Registro 3: pH
      // Registro 4: Nitrógeno
      // Registro 5: Fósforo
      // Registro 6: Potasio
      result = node.readHoldingRegisters(0x0000, 7);
      
      if (result == node.ku8MBSuccess) {
        // Humedad (%) - Registro 0 (divisor 10)
        m.soil_humidity = node.getResponseBuffer(0) / 10.0f;
        
        // Temperatura (°C) - Registro 1 (divisor 10)
        m.soil_temperature = node.getResponseBuffer(1) / 10.0f;
        
        // Conductividad (µS/cm) - Registro 2
        m.electrical_conductivity = (float)node.getResponseBuffer(2);
        
        // pH - Registro 3 (divisor 10 como en Prueba_Sensor.ino)
        m.ph = node.getResponseBuffer(3) / 10.0f;
        
        // Nitrógeno (mg/kg) - Registro 4
        m.nitrogen = node.getResponseBuffer(4);
        
        // Fósforo (mg/kg) - Registro 5
        m.phosphorus = node.getResponseBuffer(5);
        
        // Potasio (mg/kg) - Registro 6
        m.potassium = node.getResponseBuffer(6);
        
        // Leer batería
        m.battery_percent = calculateBatteryPercent();

#if ENABLE_DEBUG_SERIAL
        Serial.printf("✓ Sensor read: T=%.1f H=%.1f pH=%.1f EC=%.0f NPK=%d/%d/%d\n",
          m.soil_temperature, m.soil_humidity, m.ph, m.electrical_conductivity,
          m.nitrogen, m.phosphorus, m.potassium);
#endif
        return true;
      }

#if ENABLE_DEBUG_SERIAL
      Serial.printf("! Modbus read attempt %d failed (Error: 0x%02X)\n", attempt + 1, result);
#endif
      delay(500); // Un poco más de tiempo entre reintentos
    }

    return false;
  }

  uint8_t calculateBatteryPercent() {
    // Leer ADC del divisor de tensión en GPIO_0_DIVISOR_TENSION
    // ESP32 ADC: 0-4095 = 0-3.3V (con divisor 1:1)
    // Batería típica Li-Ion: 3.0V (0%) a 4.2V (100%)
    
    analogSetAttenuation(ADC_11db);
    uint16_t adc_value = analogRead(GPIO_0_DIVISOR_TENSION);
    
    // Convertir ADC a voltaje
    float voltage = (adc_value / 4095.0f) * 3.3f;
    
    // Mapear 3.0V - 4.2V a 0% - 100%
    float battery_percent = ((voltage - 3.0f) / (4.2f - 3.0f)) * 100.0f;
    
    // Limitar a 0-100
    if (battery_percent < 0) battery_percent = 0;
    if (battery_percent > 100) battery_percent = 100;
    
    return (uint8_t)battery_percent;
  }
};

// Factory function
SensorReader* createSensorReader() {
  return new ModbusSensorReaderImpl();
}

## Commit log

2026-06-03 la web funciona los datos no
2026-06-05 La web ya funciona sin internet, solo faltan los sensores
2026-06-05 mensajes de alerta
2026-06-08 La web ya lee la sonda
2026-06-09 GPS fix & alerts
    [config.h, gps_reader.cpp, zaque_device.ino]
2026-06-09 Add files via upload
    3d STL
    [caja2.STL, case.stl]
2026-06-09 Add files via upload
    Upload gerber for pcb
